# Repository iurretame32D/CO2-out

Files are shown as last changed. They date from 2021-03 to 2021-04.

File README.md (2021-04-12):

# CO2-OUT
Iurreta LHI ikastetxeko Mantentze-lan elektronikoa heziketa zikloko ikasleek proiektu moduluan egindako lana: CO2, hezetasuna eta tenperatura neurtu eta Lora bitarez TheThingsNetworkera bidali. NodeRed erabiliz datuak erakutsi.

Iurreta Electronic Vocational Training student project: measurement of CO2, humidity and temperature. LORA TTN Communications. Dashboard via NodeRed.

## The Things Network gateway

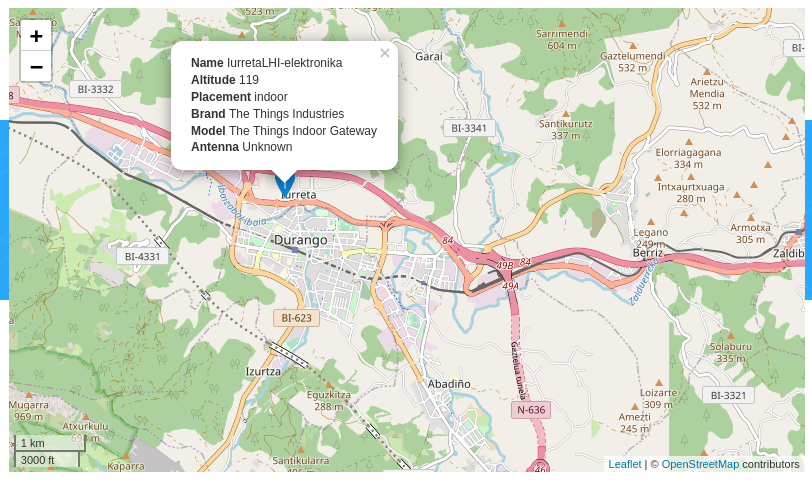
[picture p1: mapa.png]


## Bloke Diagrama / Block diagram 

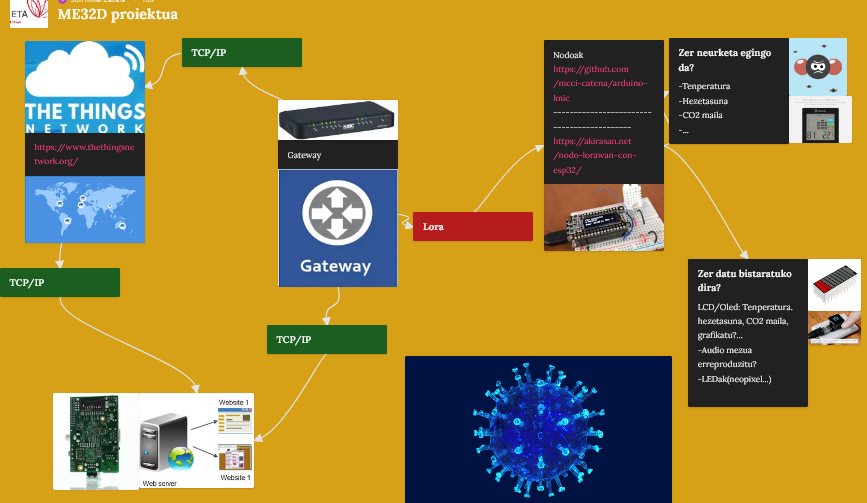
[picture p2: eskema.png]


## Emaitzak / Result
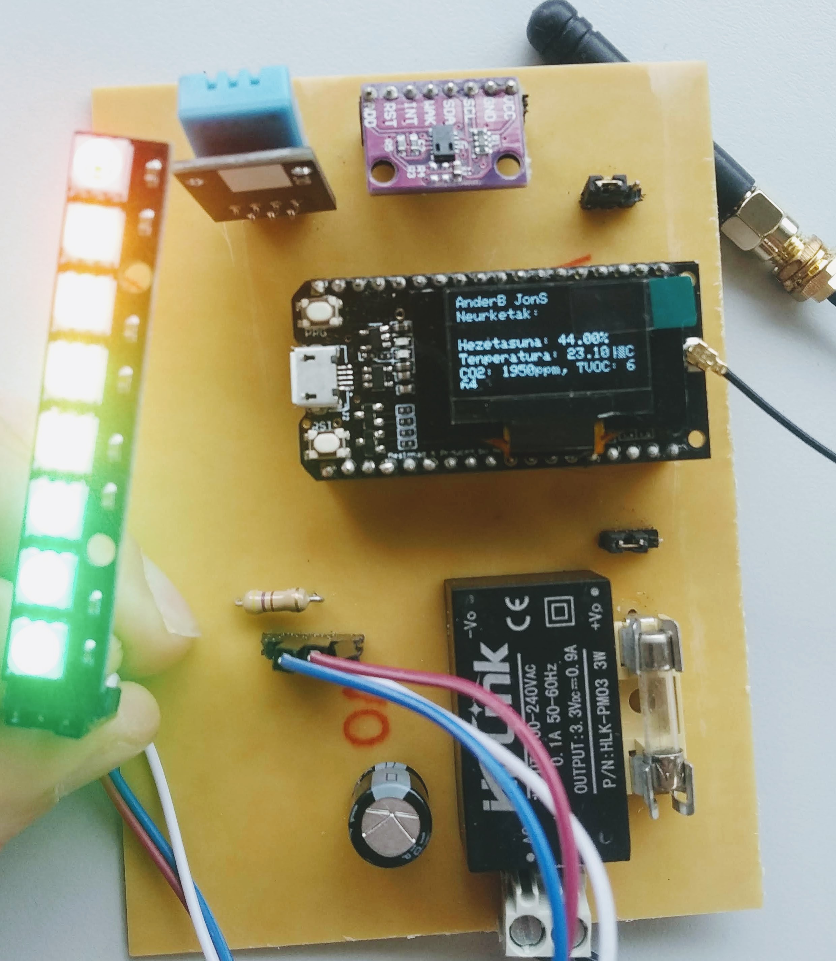
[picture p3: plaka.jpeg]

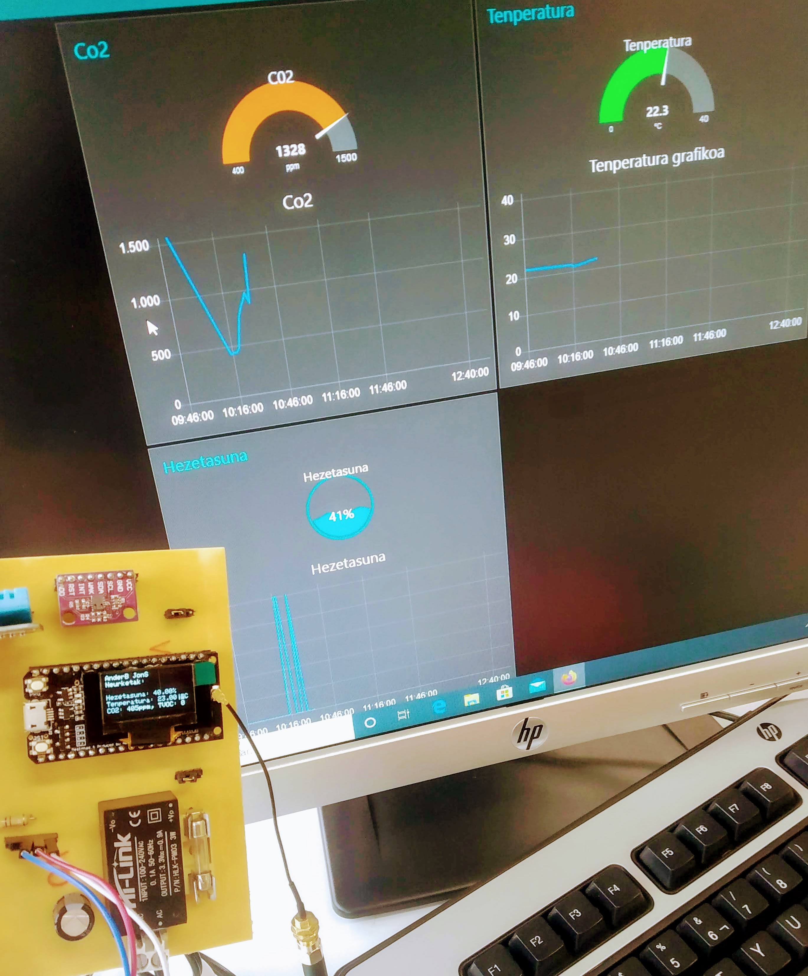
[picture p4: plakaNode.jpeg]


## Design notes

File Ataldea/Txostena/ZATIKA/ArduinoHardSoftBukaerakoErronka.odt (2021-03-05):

# Arduino nano pinen esleipena

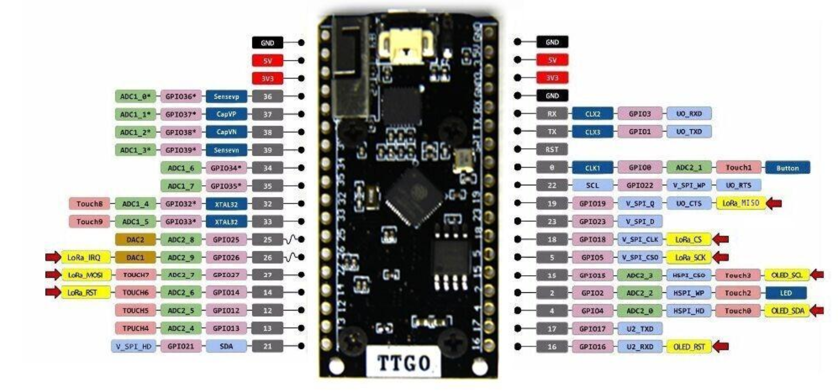
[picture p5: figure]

## 1.8. ESP-32 hardware eta software baliabideak

DIGITALA | KOMUNIKAZIOAK | GAINERAKOAK | ERABILERA
GPI0/GPO0
GPI1/GPO1 | UART TxD | | Ordenagailuarekin komunikatzeko (Serial) Datuak bidali
GPI2/GPO2
GPI3/GPO3 | UART RxD | | Ordenagailuarekin komunikatzeko (Serial) Datuak jaso
GPI4/GPO4 | SDA | | OLED_SDA ETA CJMCU-811 (CO2_Sentsorea)
GPI5/GPO5 | SPI CSO | | LORA_SCK ETA CJMCU-811 (CO2_Sentsorea)
GPI12/GPO12
GPI13/GPO13 | | | CJMCU-2812-8(Led Neopixel)
GPI14/GPO14 | | | LORA_RST
GPI15/GPO15 | SCL | | OLED_SCL
GPI16/GPO16 | U2 RXD | | OLED_RST
GPI17/GPO17 | U2 TXD | | DHT11 (Tenperatura eta Hezetasuna)
GPI18/GPO18 | SPI CLK | | LORA_CS
GPI19/GPO19 | | | LORA_MISO
GPI21/GPO21 | SDA | | CJMCU-811 (CO2_Sentsorea)
GPI22/GPO22 | SCL | | CJMCU-811 (CO2_Sentsorea)
GPI23/GPO23
GPI24/GPO24
GPI25/GPO25
GPI26/GPO26 | | | LORA_IRQ
GPI27/GPO27 | | | LORA_MOSI
GPI32/GPO32
GPI33/GPO33
GPI34/GPO34
GPI35/GPO35
GPI36/GPO36
GPI37/GPO37
GPI38/GPO38
GPI39/GPO39

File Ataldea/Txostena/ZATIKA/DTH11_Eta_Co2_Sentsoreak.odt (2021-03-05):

## 1.1 Tenperatura eta hezetasuna sentsorea

### Sarrera

DHT11 tenperatura eta hezetasun digitaleko sentsore bat da, kostu txikikoa. Hezetasun-sentsore kapazitibo bat eta termistor bat erabiltzen ditu inguruko airea neurtzeko, eta datuak seinale digital baten bidez erakusten ditu datu-pinuan (ez dago sarrerako pinu analogikorik).

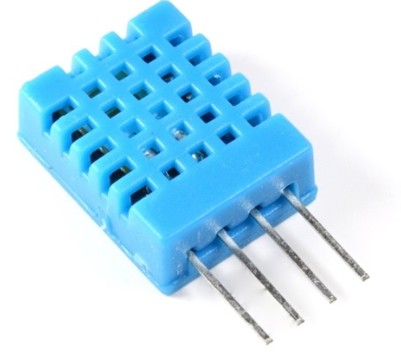
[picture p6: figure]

| Operazio-tentsioa:3V-5VDC. Tenperatura neurtzeko tartea: 0 eta 50 ° C bitartean. Tenperatura neurtzeko doitasuna: ± 2.0 ° c Denbora-ebazpena: 0.1 ° C. Hezetasuna neurtzeko tartea:% 20tik% 90era Rh. Hezetasuna neurtzeko zehaztasuna:% 5 Rh. Hezetasunaren ebazpena: Rh% 1. Sensida-denbora: 1 seg.

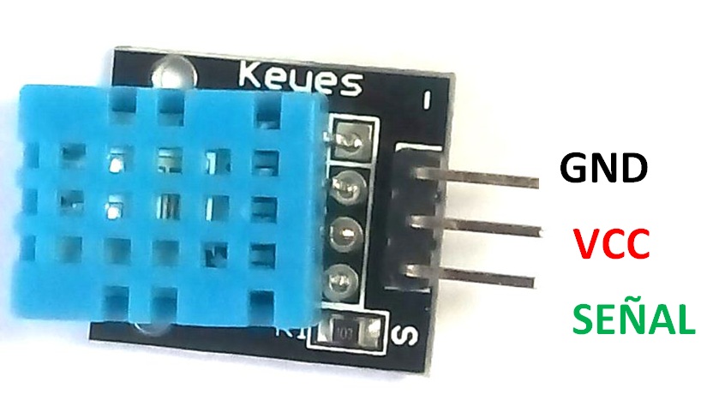
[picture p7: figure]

https://www.mouser.com/datasheet/2/758/DHT11-Technical-Data-Sheet-Translated-Version-1143054.pdf

https://www.mouser.com/datasheet/2/758/DHT11-Technical-Data-Sheet-Translated-Version-1143054.pdf

### Eskema elektronikoak

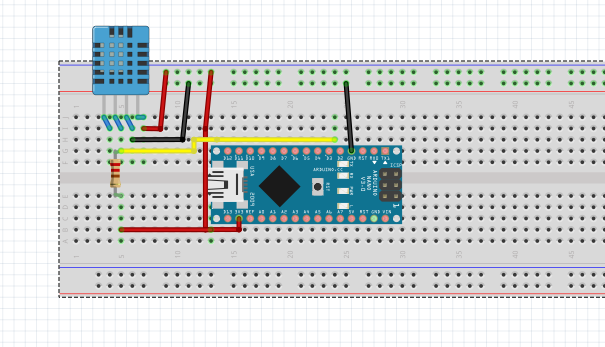
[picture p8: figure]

### Sentsorearen edo shieldaren pinout-a

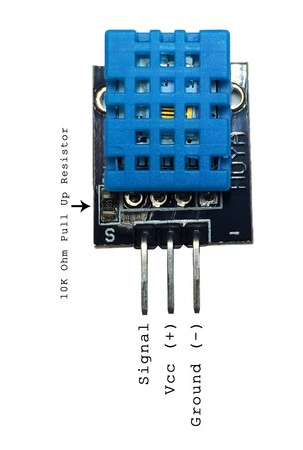
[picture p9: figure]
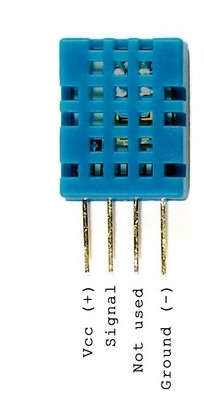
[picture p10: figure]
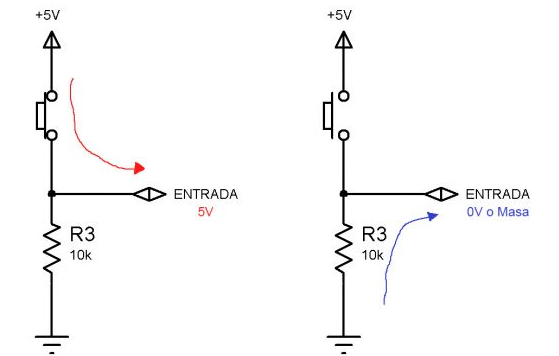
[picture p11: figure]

Sentsore hau funtzionatzeko erresitentzia bat erabili behar dugu. Erresistentzia pull up moduan jarriko dugu.

### Oinarrizko programa

Behar dugun libreria isntalatu. https://github.com/adafruit/Adafruit_Sensor

https://github.com/adafruit/DHT-sensor-library

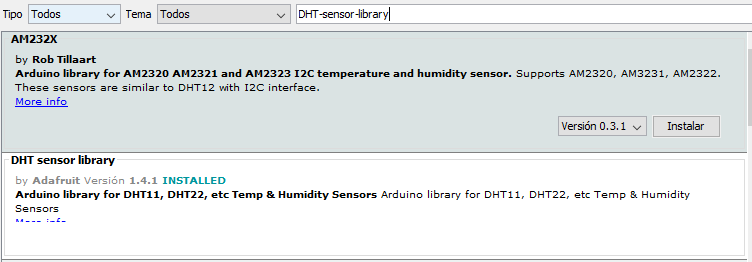
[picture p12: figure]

/*

Programaren izena: DHTtester_JON_MIKEL

Egilea: JON eta MIKEL Data: 22/02/2021

Zeregina: DHT sentsorearekin tenperatura eta hezetazuna neurtzea.

Adibide hau domeinu publikokoa da.

Programaren egoera: Egiaztatzeko/Egiaztatuta

Egiaztatutako plakak: hasiera batean Nano-arekin konprobatu dugu.

*/

/*-----( LIBURUTEGIAK )----*/

// - DHT Sensor Library: https://github.com/adafruit/DHT-sensor-library

// - Adafruit Unified Sensor Lib: https://github.com/adafruit/Adafruit_Sensor

#include <DHT.h>

#include <DHT_U.h>

#include "DHT.h"

#define DHTPIN 2 // DHT sentsoreari lotutako Digital pin

//Erabili pinak 3, 4, 5, 12, 13 edo 14.

//Pin 15ek funtziona dezake, baina DHT deskonektatu egin behar da programazioan.

/*-----( KONSTANTEAK )-----*/

#define DHTTYPE DHT11 // DHT 11

//#define DHTTYPE DHT22 // DHT 22 (AM2302), AM2321

//#define DHTTYPE DHT21 // DHT 21 (AM2301)

// Connect pin 1 (ezkerrean) of the sensor to +5V

//3.3V logika duen taula bat Arduino Due batek pin 1 konektatzen badu

//5V ordez, 3.3V!

//Zure DHTPIN DOKTOREARI

//X/Connect pin 4 (eskuinaldean)

//Connect a 10K resistor from pin 2 (datuak) to pin 1 (boterea)

//DHT sentsorea.

//Liburutegi honen bertsio zaharragoek hirugarren parametro bat eraman zuten.

//Parametro hau ez da beharrezkoa prozesadore azkarragoentzat.

//DHT irakurgailuaren algoritmoa prozesu azkarragoetan lan egitera egokitzen da.

//DHT dht(DHTPIN, DHTTYPE);

void setup() {

Serial.begin(9600);

Serial.println(F("DHTxx test!"));

dht.begin();

}

void loop() {

// Wait a few seconds between measurements.

delay(2000);

// Reading temperature or humidity takes about 250 milliseconds!

// Sensor readings may also be up to 2 seconds 'old' (its a very slow sensor)

float h = dht.readHumidity();

// Read temperature as Celsius (the default)

float t = dht.readTemperature();

// Read temperature as Fahrenheit (isFahrenheit = true)

float f = dht.readTemperature(true);

// Check if any reads failed and exit early (to try again).

if (isnan(h) || isnan(t) || isnan(f)) {

Serial.println(F("Failed to read from DHT sensor!"));

return;

}

// Compute heat index in Fahrenheit (the default)

float hif = dht.computeHeatIndex(f, h);

// Compute heat index in Celsius (isFahreheit = false)

float hic = dht.computeHeatIndex(t, h, false);

Serial.print(F("hezetasuna: "));

Serial.print(h);

Serial.print(F("% Temperatura: "));

Serial.print(t);

Serial.print(F("°C "));

Serial.print(f);

Serial.print(F("°F Bero-indizea: "));

Serial.print(hic);

Serial.print(F("°C "));

Serial.print(hif);

Serial.println(F("°F"));

}

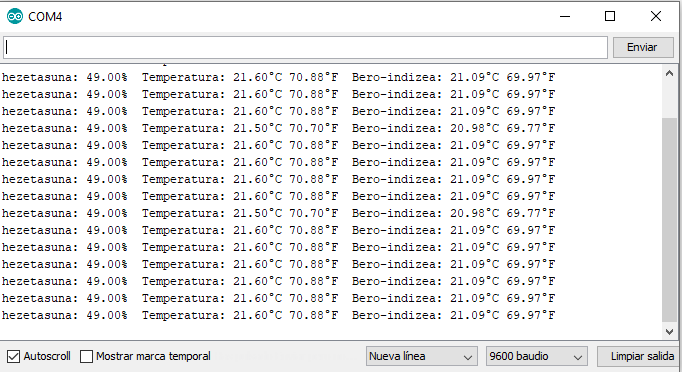
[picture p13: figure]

### Oinarrizko programa funtzioak bihurtuta

/* Funtzioa: int DTH11sentsorea (int zeinPin)

* Zeregina: DTH11 sentsorean temperatura eeta hezetasuna naurtzen du.

* Erabilitako liburutegiak: DTH11DHT Sensor Library eta Adafruit

* Liburutegia nondik hartuta: https://github.com/adafruit/Adafruit_Sensor // https://github.com/adafruit/DHT-sensor-library

* Bueltatzen duena: ezer

* Sartutako parametroak:

* int

*

* */

void DTH11sentsoreaSETUP (void){

Serial.println(F("DHTxx test!"));

dht.begin();

}

/* Funtzioa: int DTH11sentsorea (int zeinPin)

* Zeregina: DTH11 sentsorean temperatura eeta hezetasuna naurtzen du.

* Erabilitako liburutegiak: DTH11DHT Sensor Library eta Adafruit

* Liburutegia nondik hartuta: https://github.com/adafruit/Adafruit_Sensor // https://github.com/adafruit/DHT-sensor-library

* Bueltatzen duena: ezer

* Sartutako parametroak:

* int

*

* */

void DTH11sentsoreaLOOP (void){

// Wait a few seconds between measurements.

delay(2000);

// Reading temperature or humidity takes about 250 milliseconds!

// Sensor readings may also be up to 2 seconds 'old' (its a very slow sensor)

float h = dht.readHumidity();

// Read temperature as Celsius (the default)

float t = dht.readTemperature();

// Read temperature as Fahrenheit (isFahrenheit = true)

float f = dht.readTemperature(true);

// Check if any reads failed and exit early (to try again).

if (isnan(h) || isnan(t) || isnan(f)) {

Serial.println(F("Failed to read from DHT sensor!"));

return;

}

// Compute heat index in Fahrenheit (the default)

float hif = dht.computeHeatIndex(f, h);

// Compute heat index in Celsius (isFahreheit = false)

float hic = dht.computeHeatIndex(t, h, false);

Serial.print(F("hezetasuna: "));

Serial.print(h);

Serial.print(F("% Temperatura: "));

Serial.print(t);

Serial.print(F("°C "));

Serial.print(f);

Serial.print(F("°F Bero-indizea: "));

Serial.print(hic);

Serial.print(F("°C "));

Serial.print(hif);

Serial.println(F("°F"));

}

### Material zerrenda

Izena | Kopurua | Oharrak edota ezaugarri bereziak
DHT11 | 1 | Errezistentzia erabilitzen dugu. (PULL UP)
ARDUINO NANO | 1 | Sentsorea probetako erabiltzen dugu.

### Gorabeherak

### Estekak

https://steve.fi/hardware/temperature/

https://www.zonamaker.com/electronica/intro-electronica/teoria/resistencias-de-pull-up-y-pull-down

https://forum.fritzing.org/t/heltec-dev-boards/8112

https://fritzing.org/projects/dht11-temp-and-humidity-sensor

## CO2 sentsorea

### Sarrera

CCS811 sentsore bat da barneko airearen kalitatea neurtzeko, eta erraz erabil dezakegu Arduino bezalako prozesadore batekin batera.
Barneko airearen kalitatea zehazteko, CCS811 MOX (Metal-Oxide) sentsore multigas bat da, karbono monoxidoa (Co) eta konposatu lurrunkorrak (VOCs) neurtzea barne hartzen duena, hala nola etanola, aminak edo hidrokarburo aromatikoak. Horien bidez, CCS811k karbono dioxido baliokidearen (eCO2) kantitatea zehaztu dezake. Neurketa-tartea 400 eta 8192 ppm artekoa da eCO2-n eta 0 eta 1187 ppb artekoa TVOCen.

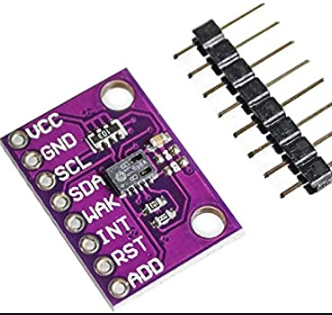
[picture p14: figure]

| Konposatu organiko lurrunkorra guztira (TVOC), milioi bakoitzeko 0 eta 1187 zati bitartean detektatzen dituena ECO2ren detekzioa, 400etik 8,192ra milioiko. Bost funtzionamendu-modu MCU integratua I2C interfaze digital estandarra Kontsumo txikiko moduak Elikadura: 3.3V a 5V Neurriak: 21 x 18 x 3 milimetro Pisua: 1.2 gramo

Datasheet-ak ez du neurketaren zehaztasunari buruzko daturik ematen.

https://cdn.sparkfun.com/assets/2/c/c/6/5/CN04-2019_attachment_CCS811_Datasheet_v1-06.pdf

### Eskema elektronikoak

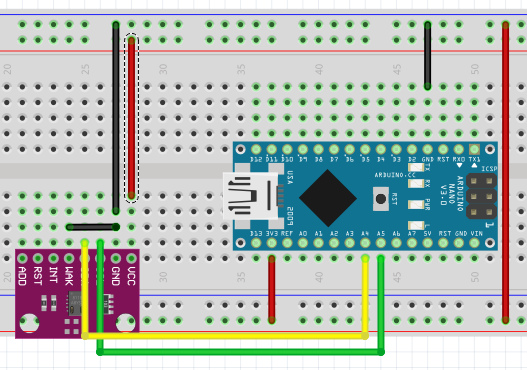
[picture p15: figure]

### Sentsorearen edo shieldaren pinout-a

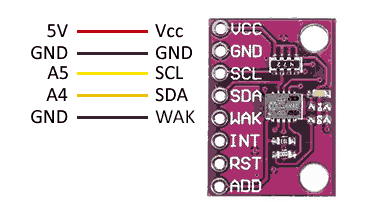
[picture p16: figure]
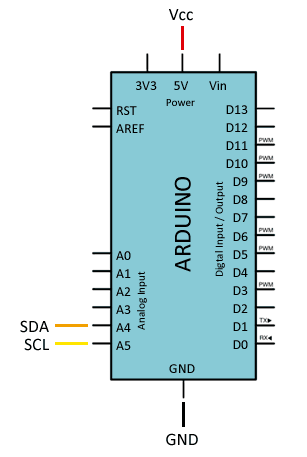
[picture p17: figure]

### Oinarrizko programa

Behar dugun lebreria istalatu. //https://github.com/adafruit/Adafruit_CCS811

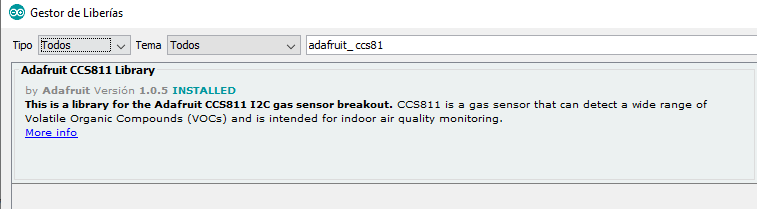
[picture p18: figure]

/*

Programaren izena: DHTtester_JON_MIKEL

Egilea: JON eta MIKEL Data: 22/02/2021

Zeregina: DHT sentsorearekin tenperatura eta hezetazuna neurtzea.

Adibide hau domeinu publikokoa da.

Programaren egoera: Egiaztatzeko/Egiaztatuta

Egiaztatutako plakak: hasiera batean Nano-arekin konprobatu dugu.

*/

/*-----( LIBURUTEGIAK )----*/

#include "Adafruit_CCS811.h" //https://github.com/adafruit/Adafruit_CCS811

Adafruit_CCS811 ccs;

void setup() {

Serial.begin(9600);

Serial.println("CCS811 test");

if(!ccs.begin()){

Serial.println("Failed to start sensor! Please check your wiring.");

while(1);

}

// Wait for the sensor to be ready

while(!ccs.available());

}

void loop() {

if(ccs.available()){

if(!ccs.readData()){

//Serial.println(ccs.calculateTemperature());

Serial.print("ºC, CO2: ");

Serial.print(ccs.geteCO2());

Serial.print("ppm, TVOC: ");

Serial.println(ccs.getTVOC());

}

else{

Serial.println("ERROR!");

while(1);

}

}

delay(500);

}

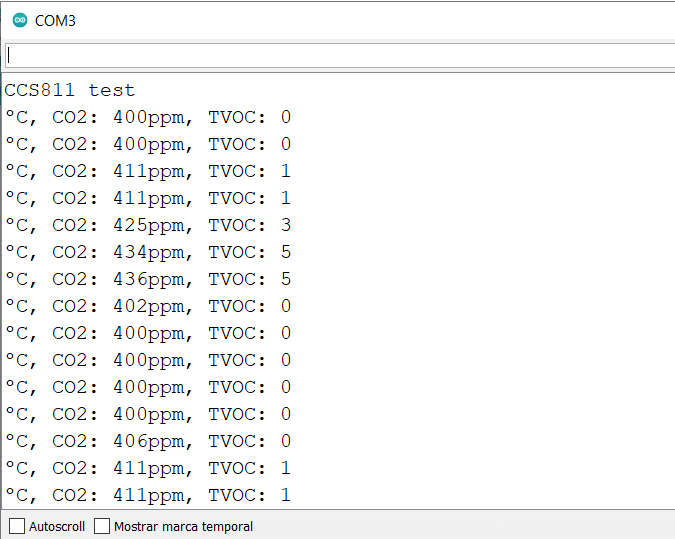
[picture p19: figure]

### Oinarrizko programa funtzioak bihurtuta

/* Funtzioa: void CO2sentsorea (void)

* Zeregina:CO2 sentsorean naurtzea du.

* Erabilitako liburutegiak: DTH11DHT Sensor Library eta Adafruit

* Liburutegia nondik hartuta://https://github.com/adafruit/Adafruit_CCS811

* Bueltatzen duena: ezer

* Sartutako parametroak:

* int

*

* */

void CO2sentsoreaSETUP (void){

Serial.println("CCS811 test");

if(!ccs.begin()){

Serial.println("Failed to start sensor! Please check your wiring.");

while(1);

}

// Wait for the sensor to be ready

while(!ccs.available());

}

/* Funtzioa: void CO2sentsorea (void)

* Zeregina:CO2 sentsorean naurtzea du.

* Erabilitako liburutegiak: DTH11DHT Sensor Library eta Adafruit

* Liburutegia nondik hartuta://https://github.com/adafruit/Adafruit_CCS811

* Bueltatzen duena: ezer

* Sartutako parametroak:

* int

*

* */

void CO2sentsoreaLOOP (void){

if(ccs.available()){

if(!ccs.readData()){

//Serial.println(ccs.calculateTemperature());

Serial.print("CO2: ");

Serial.print(ccs.geteCO2());

Serial.println("ppm");

Serial.print("TVOC: ");

Serial.println(ccs.getTVOC());

}

else{

Serial.println("ERROR!");

while(1);

}

}

delay(500);

}

### Material zerrenda

Izena | Kopurua | Oharrak edota ezaugarri bereziak
CO2 (Sentsorea) | 1
ARDUINO NANO | 1 | Sentsorea probetako erabiltzen dugu.

### Gorabeherak

### Estekak

https://www.luisllamas.es/medir-calidad-del-aire-y-co2-con-ccs811-y-arduino/

https://tienda.bricogeek.com/sensores-gas/1508-sensor-de-calidad-del-aire-ccs811-voc-y-co2.html

http://digitalconcepts.net.au/fritzing/index.php?op=parts

20-21 ikasturtea Erronkaren azpiatala

IURRETA LHI Ikastetxea 11. orrialdea

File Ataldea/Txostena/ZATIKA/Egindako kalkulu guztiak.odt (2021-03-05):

# Egindako kalkulu guztiak

## Elikatze-iturriaren kalkuluak

Gure osagai guztiak zenbateko elikadura behar dituen eta zenbat mA erabiltzen dituen. Taula honetan adierazten dugu.

PLAKAKO ELIKADURA | | | | | KANPOKO ELIKADURA | | ERABILERA
VIN | 5V | 3V3 | GND | RESET | V | mA
| | X | | | 3V3 | 20mA | TT-GO-ESP32
| | X | | | | 4.5mA | CCS811 (CO2 Sentsorea)
| | X | | | | 2.5mA | DHT11 (Tenperatura eta Hezetasuna Sentsorea)
| | X | | | | 900mA | Neopixel
12 voltio | | | | | 220 | 1100%20220mA | Bateria DC

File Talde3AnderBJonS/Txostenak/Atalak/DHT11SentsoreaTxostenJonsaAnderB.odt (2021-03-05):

## DHT-11

### Sarrera

DHT-11 erabiliko ditugun sentsoreetako bat izango da, sentsore hau tenperatura eta hezetasuna neurtzuko balio du, gure kasuan erabiliko duguna 3 pin ditu, eskumako irudian ikusten denez.

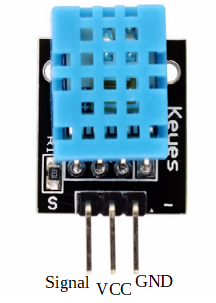
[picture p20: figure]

Tenperatura ºCtan neurtzen du eta hezetasuna %tan.

Kostu txikiko eta erabiltzeko erraza den sentsorea da.Hezetasun kapazitarioaren sentsorea eta termistore bat integratzen ditu inguruko airea neurtzeko, eta datuak seinale digital baten bidez erakusten ditu signal pinean (ez du irteera analogikorik).

Datasheet Link

https://components101.com/sites/default/files/component_datasheet/DHT11-Temperature-Sensor.pdf

Ezaugarriak:

- Kontsumoa = 2,5mA
- Irteera seinalea = Digitala
- Tenperatura maila = 0ºC – 50ºC
- Hezetasun maila = 20 % - 90 %

### Eskema elektronikoak

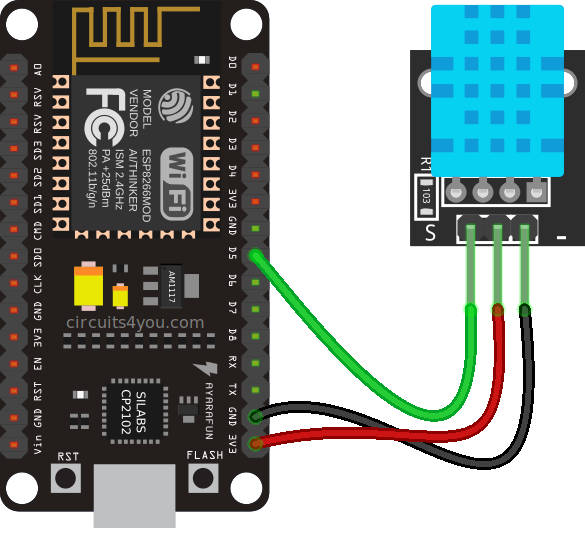
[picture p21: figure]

### Sentsorearen edo shieldaren pinout-a

Berezitasunik balego adierazi hemen (pull-up erresistentziak, tentsio balioen mugak...)

### Oinarrizko programa

#include "DHT.h"

// Uncomment whatever type you're using!

#define DHTTYPE DHT11 // DHT 11

//#define DHTTYPE DHT22 // DHT 22 (AM2302), AM2321

//#define DHTTYPE DHT21 // DHT 21 (AM2301)

// Connect pin 1 (on the left) of the sensor to +5V

// NOTE: If using a board with 3.3V logic like an Arduino Due connect pin 1

// to 3.3V instead of 5V!

// Connect pin 2 of the sensor to whatever your DHTPIN is

// Connect pin 4 (on the right) of the sensor to GROUND

// Connect a 10K resistor from pin 2 (data) to pin 1 (power) of the sensor

const int DHTPin = 5; // what digital pin we're connected to

DHT dht(DHTPin, DHTTYPE);

void setup() {

Serial.begin(9600);

Serial.println("DHTxx test!");

dht.begin();

}

void loop() {

// Wait a few seconds between measurements.

delay(2000);

// Reading temperature or humidity takes about 250 milliseconds!

float h = dht.readHumidity();

float t = dht.readTemperature();

if (isnan(h) || isnan(t)) {

Serial.println("Failed to read from DHT sensor!");

return;

}

Serial.print("Humidity: ");

Serial.print(h);

Serial.print(" %\t");

Serial.print("Temperature: ");

Serial.print(t);

Serial.println(" *C ");

}

### Oinarrizko programa funtzioak bihurtuta

Nagusia:

/*-----( LIBURUTEGIAK )----*/

//CO2

#include "Adafruit_CCS811.h"

Adafruit_CCS811 ccs;

//DHT11

#include "DHT.h"

/*-----( KONSTANTEAK )-----*/

#define DHTTYPE DHT11 // DHT 11

const int DHTPin = 5; // what digital pin we're connected to

/*-----( OBJETUAK )-----*/

//DHT-11

DHT dht(DHTPin, DHTTYPE);

/*-----( ALDAGAIAK )----*/

//Programa osoan zehar erabiliko diren aldagai orokorrak

//Komunikazio serierako aldagaiak

/*-----( FUNTZIOAK )----*/

float dhtSentsoreaLoop(void);

void CO2SentsoreaLoop();

void C02SentsoreaSetup();

void dhtSentsoreaSetup();

void setup() {

// put your setup code here, to run once:

Serial.begin(9600);

dhtSentsoreaSetup();

C02SentsoreaSetup();

}

void loop() {

dhtSentsoreaLoop();

CO2SentsoreaLoop();

}

// put your main code here, to run repeatedly:

CO2:

/* Funtzioa: CO2 sentsorea

* Zeregina: Funtzio honek C02 sentsoreak neurtutako balioak irakurtzeko

* Erabilitako liburutegiak: https://github.com/adafruit/Adafruit_CCS811

* Bueltatzen duena: C02 eta TVOC neurketa

* Sartutako parametroak: ezer

* */

void C02SentsoreaSetup()

{

Serial.println("CCS811 test");

if(!ccs.begin()){

Serial.println("Failed to start sensor! Please check your wiring.");

while(1);

}

while(!ccs.available());

}

void CO2SentsoreaLoop() {

if(ccs.available()){

if(!ccs.readData()){

Serial.print("CO2: ");

Serial.print(ccs.geteCO2());

Serial.print("ppm, TVOC: ");

Serial.println(ccs.getTVOC());

}

else{

Serial.println("ERROR!");

while(1);

}

}

delay(500);

}

DHT-11:

/* Funtzioa: DHT-11 sentsorea

* Zeregina: Funtzio honek DHT-11 sentsoreak neurtutako balioak irakurtzeko

* Erabilitako liburutegiak: https://github.com/adafruit/DHT-sensor-library

* Bueltatzen duena: Tenperatura eta hezetasun neurketa

* Sartutako parametroak: ezer

* */

void dhtSentsoreaSetup()

{

Serial.println("DHTxx test!");

dht.begin();

}

float dhtSentsoreaLoop(void) {

// Wait a few seconds between measurements.

delay(2000);

// Reading temperature or humidity takes about 250 milliseconds!

float h = dht.readHumidity();

float t = dht.readTemperature();

if (isnan(h) || isnan(t)) {

Serial.println("Failed to read from DHT sensor!");

return;

}

Serial.print("Humidity: ");

Serial.print(h);

Serial.print(" %\t");

Serial.print("Temperature: ");

Serial.print(t);

Serial.println(" *C ");

}

### Material zerrenda

Nahi duzuen formatuan, sistema hau gauzatzeko material zerrenda. Gutxienez, azpiko taulan agertzen diren atalak agertu behar dira:

Izena | Kopurua | Oharrak edota ezaugarri bereziak
DHT-11 | 1 | 3 pin
ESP32 kontrolagailua | 1 | Nodo

### Gorabeherak

Ez ditugu izan gorabeherarik atal honetan

ME3Titulua

# ME3Kapitulua

## ME3Azpikapitulua1

### ME3Azpikapitulua2

#### ME3Azpikapitulua3

##### ME3Azpikapitulua4

###### ME3Azpikapitulua5

###### ME3Azpikapitulua6

ME3Arrunta

- ME3Buleta1

ME3Taula

ME3IrudiAzpi

20-21 ikasturtea Erronkaren azpiatala

IURRETA LHI Ikastetxea 7. orrialdea

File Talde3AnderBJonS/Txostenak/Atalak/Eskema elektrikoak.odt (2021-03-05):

# Eskema elektrikoak

Kicad eskema

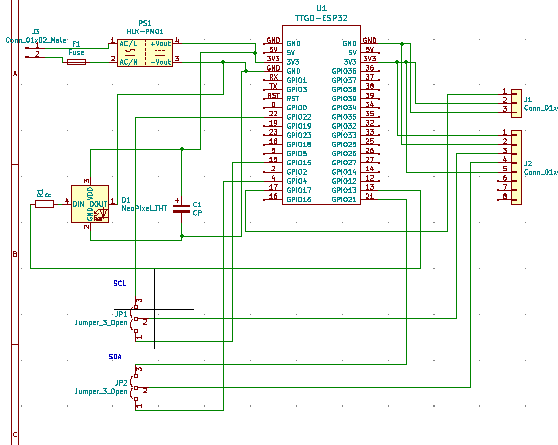
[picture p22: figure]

PCB eskema

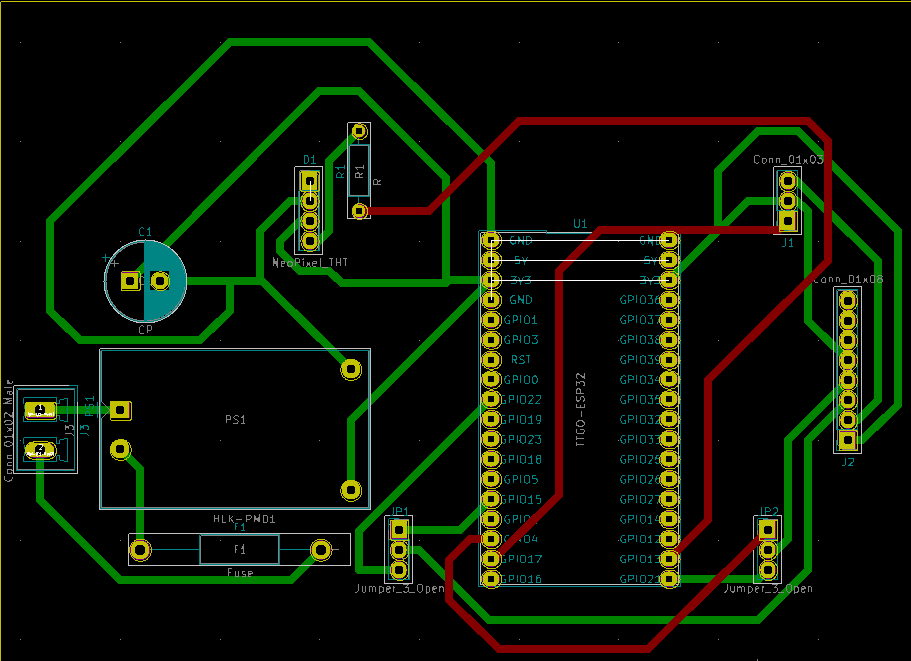
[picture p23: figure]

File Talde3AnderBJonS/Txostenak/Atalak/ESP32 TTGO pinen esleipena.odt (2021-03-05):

# ESP32 TTGO pinen esleipena

PLAKAKO ELIKADURA | | | | | KANPOKO ELIKADURA | | ERABILERA
VIN | 5V | 3V3 | GND | RESET | V | mA
| | | | | 3,3 | 20 | TTGO Lora
| | X | | | | 2,5 | DHT11 (Tenperatura eta Hezetasuna)
| | X | | | | 10 | CJMCU-811(CO2_Sentsorea)
| | X | | | | 480 | LED NEOPIXEL
| | | | | 220 V | 900 | HLK-PM03 AC-DC 220 V a 3,3V

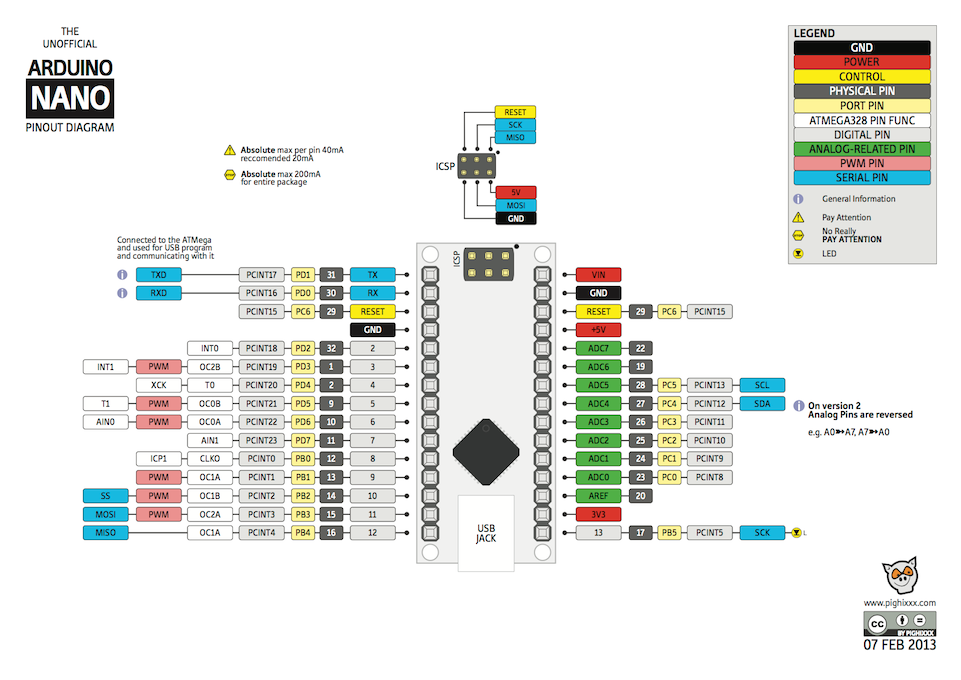
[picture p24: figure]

DIGITALA | KOMUNIKAZIOAK | GAINERAKOAK | ERABILERA
GPI0/GPO0
GPI1/GPO1 | UART TxD | | Ordenagailuarekin komunikatzeko (Serial) Datuak jaso
GPI2/GPO2
GPI3/GPO3 | UART RxD | | Ordenagailuarekin komunikatzeko (Serial) Datuak bidali
GPI4/GPO4 | SDA | | OLED_SDA--CJMCU-811(CO2_Sentsorea)
GPI5/GPO5 | SPI CSO | | LORA_SCK
GPI12/GPO12
GPI13/GPO13 | | | LED NEOPIXEL
GPI14/GPO14 | | | LORA_RST
GPI15/GPO15 | SCL | | OLED_SCL--CJMCU-811(CO2_Sentsorea)
GPI16/GPO16 | U2 RXD | | OLED_RST
GPI17/GPO17 | U2 TXD | | DHT11 (Tenperatura eta Hezetasuna)
GPI18/GPO18 | SPI CLK | | LORA_CS
GPI19/GPO19 | | | LORA_MISO
GPI21/GPO21 | SDA(jumper) | | CJMCU-811(CO2_Sentsorea)
GPI22/GPO22 | SCL(jumper) | | CJMCU-811(CO2_Sentsorea)
GPI23/GPO23
GPI24/GPO24
GPI25/GPO25
GPI26/GPO26 | | | LORA_IRQ
GPI27/GPO27 | | | LORA_MOSI
GPI32/GPO32
GPI3/GPO33
GPI34/GPO34
GPI35/GPO35

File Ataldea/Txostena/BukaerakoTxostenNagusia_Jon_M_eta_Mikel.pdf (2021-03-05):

# LORA

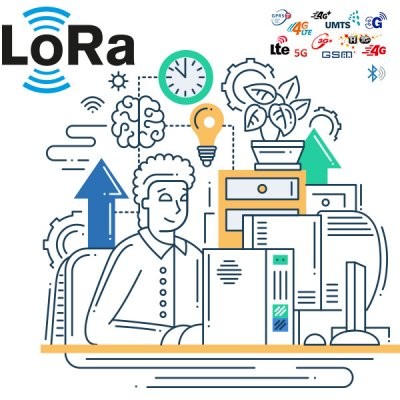
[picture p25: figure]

Egileak

Jon M eta Mikel

1. orrialdea
lan hau IURRETA LHIIk sortu du eta Creative Commons lizentzia (https://creativecommons.org/licenses/by-nc/4.0/deed.eu) baten mende dago.

## Ziklo bukaerako proiektua: aurkibidea

2. orrialdea

# 1 Erronkaren planteamentua

Erronka honetan bidali digute co2, tenperatura eta hezetasuna neurtzea eta honek datuak prosesatzeko Lora esp32 kontrolagailua. Datu honekin lortu behar duguna da WEB SERVER batean irakur ahal izatea eta ona heltzeko hainbat pausu pasatu behar dugu. Lehenik datuak GATEWAY batera bidaltzea eta irakurtzea, ostean RASPERRRY locala sortu.
Erronka bukatzen dugunean github plataformara dena dokumentatu eta programa osoak igo beharko dugu.

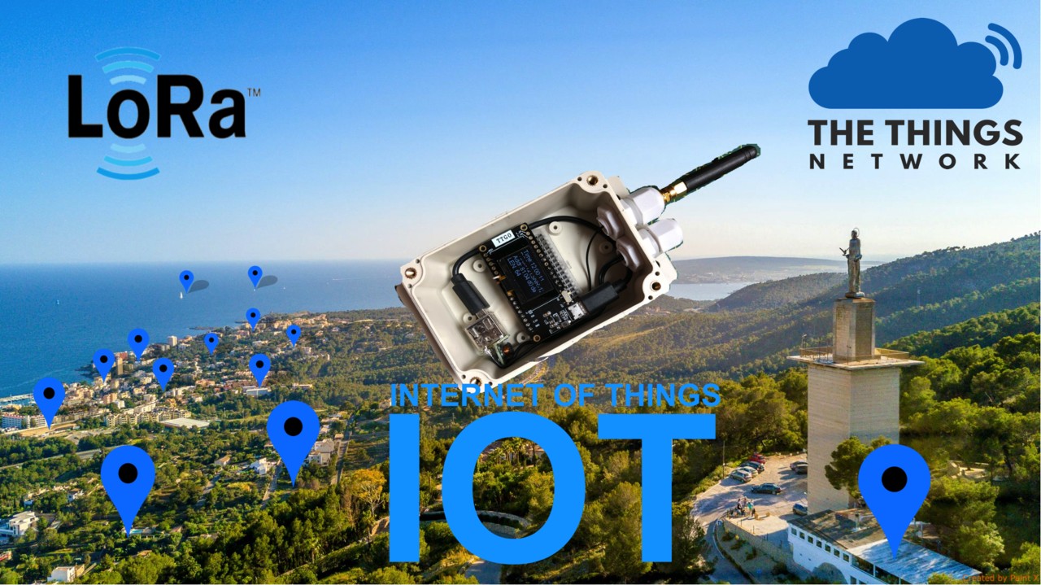
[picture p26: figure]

3. orrialdea

# 2 Bloke-diagramak

Lehen bertsioa izango da hau. Erronkaren amaieran igo egingo duzue azken bertsioa.

# 2.1 Softwarearen hasierako bloke-diagrama

Softwarea: geziekin, bloke bakoitza zelan eta zertarako erabiliko den azalduta azpian. Aldagaiak eta funtzioen izenak aurreikustea ere komeniko litzateke. Sekuentzia edo ordena inportantea dela kontutan izan.

4. orrialdea

# 2.2 Hardwarearen hasierako bloke-diagram

Hardwarea: geziekin, bloke bakoitza zelan eta zertarako erabiliko den azalduta azpian.

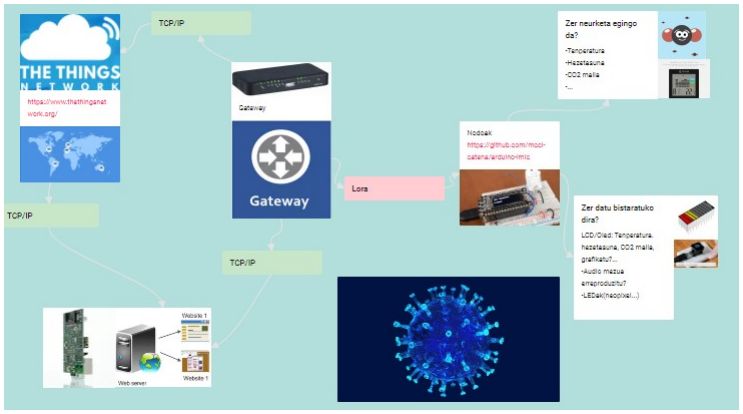
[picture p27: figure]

5. orrialdea

# 2.3 Softwarearen amaierako bloke-diagrama

Softwarea: geziekin, bloke bakoitza zelan eta zertarako erabiliko den azalduta azpian. Aldagaiak eta funtzioen izenak aurreikustea ere komeniko litzateke. Sekuentzia edo ordena inportantea dela kontutan izan.

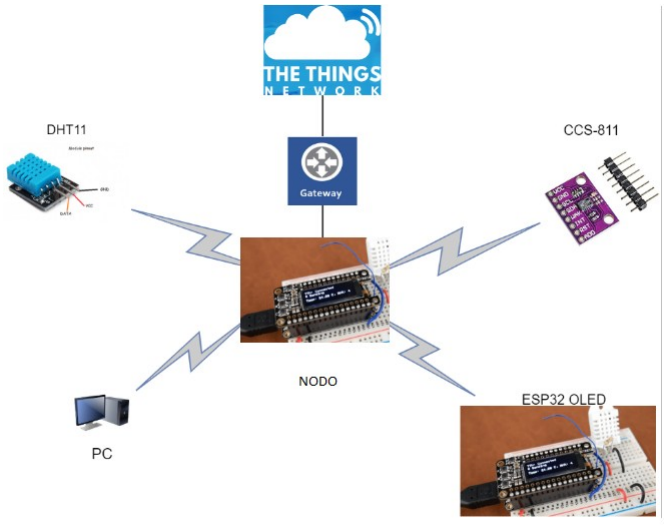
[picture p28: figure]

6. orrialdea

# 2.4 Hardwarearen amaierako bloke-diagrama

Hardwarea: geziekin, bloke bakoitza zelan eta zertarako erabiliko den azalduta azpian.


7. orrialdea

# 3 Haunarketa

## LORA ESP32

- Norabide bakarreko, norabide biko edo hedapen anitzeko lan-gaitasuna
- Interferentziekiko tolerantzia handia
- Sentsibilitate handia datuak jasotzeko (-168dB)
"Chirp" modulazioan oinarritua
- Kontsumo baxua (10 urtera arte bateria batekin)
- Luzera: 10-20 km
- Datuen transferentzia txikia (255 byte gehienez)
- Puntuz puntuko konexioa
- Lan maiztasunak: 868 Mhz Europan, 915 Mhz Amerikan eta 433 Mhz Asian
8. orrialdea

DH11

- DHT11 eta DHT22 (edo AM2302) sentsore familia bereko bi modelo dira, tenperatura eta hezetasuna aldi berean neurtzeko aukera ematen dutenak.
- Sentsore horiek barne-prozesadore bat dute, neurketa-prozesua egiten duena, eta neurketa seinale digital baten bidez ematen dute; beraz, oso erraza da neurketa Arduino bezalako mikroprozesadore batetik lortzea.
- Bi sentsoreek antzeko plastikozko kapsulatzea dute. Bi ereduak kolorearen arabera bereiz ditzakegu. DHT11ak karkasa urdin bat du, DHT22 sentsorearen kasuan, berriz, kanpoaldea zuria da.


9. orrialdea

## CCS811

- CCS811 AMS fabrikatzailearen sentsore bat da barneko airearen kalitatea neurtzeko, eta erraz erabil dezakegu Arduino bezalako prozesadore batekin batera.
- Barneko airearen kalitatea zehazteko, CCS811 MOX (Metal-Oxide) sentsore multigas bat da, karbono monoxidoa (Co) eta konposatu lurrunkorrak (VOCs) neurtzea barne hartzen duena, hala nola etanola, aminak edo hidrokarburo aromatikoak.
- Horien bidez, CCS811k karbono dioxido baliokidearen (eCO2) kantitatea zehaztu dezake. Neurketa-tartea 400 eta 8192 ppm artekoa da eCO2-n eta 0 eta 1187 ppb artekoa TVOCen. Datasheet-ak ez du neurketaren zehaztasunari buruzko daturik ematen.


10. orrialdea

# 4 Lora TTGO esp32

# 4.1 Sarrera

TTGO LoRa32 SX1276 OLED garapen plaka bat da, LoRa txip bat eta 0,96 hazbeteko OLED SSD1306 pantaila dituena. Gida honetan erakutsiko dizugu nola bidali eta jaso LoRa paketeak (puntuz puntuko komunikazioa) eta nola erabili OLED pantaila Arduino IDErekin.


11. orrialdea

# 4.2 Lora liburutegiak

Lora esp32 erabili ahal izateko hainbat librería instalatu behar dira eta orain esteka bidez eta argazki bidez adieraziko dizuet.

Asteko lora funtzionatzeko hainbat librería istalatu behar dira eta esteka honetatik pausuak jarraitzen atera ditugu:

https://randomnerdtutorials.com/ttgo-lora32-sx1276-arduino-ide/https://github.com/matthijskooijman/arduino-lmic.git

https://randomnerdtutorials.com/installing-the-esp32-board-in-arduino-ide-windows-instructions/


12. orrialdea

# 4.3 Lora probak

Lora probatzeko programa bat sartu diogu, nun programa hau 10segunduro mezuak bidaltzen ditu beste dispositibo batera.
/*********
Rui Santos
Complete project details at https://RandomNerdTutorials.com/ttgo-lora32-sx1276-arduino-ide/
*********/
//Libraries for LoRa
#include <SPI.h>

#include <LoRa.h>

//Libraries for OLED Display #include <Wire.h>
#include <Adafruit_GFX.h>

#include <Adafruit_SSD1306.h>

//define the pins used by the LoRa transceiver module #define SCK 5
#define MISO 19

#define MOSI 27

#define SS 18

#define RST 14

#define DIO0 26

//433E6 for Asia
//866E6 for Europe
//915E6 for North America
#define BAND 866E6

//OLED pins
#define OLED_SDA 4

#define OLED_SCL 15

#define OLED_RST 16

#define SCREEN_WIDTH 128 // OLED display width, in pixels #define SCREEN_HEIGHT 64 // OLED display height, in pixels

//packet counter
int counter = 0;
Adafruit_SSD1306 display(SCREEN_WIDTH, SCREEN_HEIGHT, &Wire, OLED_RST); void setup() {
//reset OLED display via software
13. orrialdea pinMode(OLED_RST, OUTPUT); digitalWrite(OLED_RST, LOW); delay(20);
digitalWrite(OLED_RST, HIGH);
//initialize OLED
Wire.begin(OLED_SDA, OLED_SCL);
if(!display.begin(SSD1306_SWITCHCAPVCC, 0x3c, false, false)) { // Address 0x3C for 128x32
Serial.println(F("SSD1306 allocation failed"));
for(;;); // Don't proceed, loop forever
}
display.clearDisplay();
display.setTextColor(WHITE); display.setTextSize(1);
display.setCursor(0,0);
display.print("LORA SENDER "); display.display();
//initialize Serial Monitor Serial.begin(115200);
Serial.println("LoRa Sender Test"); //SPI LoRa pins
SPI.begin(SCK, MISO, MOSI, SS); //setup LoRa transceiver module LoRa.setPins(SS, RST, DIO0);
if (!LoRa.begin(BAND)) {
Serial.println("Starting LoRa failed!"); while (1);
}
Serial.println("LoRa Initializing OK!"); display.setCursor(0,10);
display.print("LoRa Initializing OK!"); display.display();
delay(2000);
}
void loop() {
Serial.print("Sending packet: "); Serial.println(counter);
14. orrialdea

//Send LoRa packet to receiver LoRa.beginPacket();
LoRa.print("hello ");
LoRa.print(counter);
LoRa.endPacket();
display.clearDisplay();
display.setCursor(0,0);
display.println("LORA SENDER"); display.setCursor(0,20);
display.setTextSize(1);
display.print("LoRa packet sent."); display.setCursor(0,30);
display.print("Counter:"); display.setCursor(50,30);
display.print(counter);
display.display();
counter++;
delay(10000);}
15. orrialdea

Mezu honek jasotzeko beste programa bat kargatu behar da.
/*********
Rui Santos
Complete project details at https://RandomNerdTutorials.com/ttgo-lora32-sx1276-arduino-ide/
//Libraries for LoRa
#include <SPI.h>

#include <LoRa.h>

//Libraries for OLED Display #include <Wire.h>
#include <Adafruit_GFX.h>

#include <Adafruit_SSD1306.h>

//define the pins used by the LoRa transceiver module #define SCK 5
#define MISO 19

#define MOSI 27

#define SS 18

#define RST 14

#define DIO0 26

//433E6 for Asia
//866E6 for Europe
//915E6 for North America
#define BAND 866E6

//OLED pins
#define OLED_SDA 4

#define OLED_SCL 15

#define OLED_RST 16

#define SCREEN_WIDTH 128 // OLED display width, in pixels

#define SCREEN_HEIGHT 64 // OLED display height, in pixels Adafruit_SSD1306 display(SCREEN_WIDTH, SCREEN_HEIGHT, &Wire, OLED_RST); String LoRaData;

void setup() {
//reset OLED display via software
pinMode(OLED_RST, OUTPUT); digitalWrite(OLED_RST, LOW); delay(20);
digitalWrite(OLED_RST, HIGH);
16. orrialdea

//initialize OLED
Wire.begin(OLED_SDA, OLED_SCL);
if(!display.begin(SSD1306_SWITCHCAPVCC, 0x3c, false, false)) { // Address 0x3C for 128x32
Serial.println(F("SSD1306 allocation failed"));
for(;;); // Don't proceed, loop forever
}
display.clearDisplay();
display.setTextColor(WHITE); display.setTextSize(1);
display.setCursor(0,0);
display.print("LORA RECEIVER "); display.display();
//initialize Serial Monitor Serial.begin(115200);
Serial.println("LoRa Receiver Test"); //SPI LoRa pins
SPI.begin(SCK, MISO, MOSI, SS); //setup LoRa transceiver module LoRa.setPins(SS, RST, DIO0);
if (!LoRa.begin(BAND)) {
Serial.println("Starting LoRa failed!"); while (1);
}
Serial.println("LoRa Initializing OK!"); display.setCursor(0,10);
display.println("LoRa Initializing OK!"); display.display();
}
void loop() {
//try to parse packet
int packetSize = LoRa.parsePacket(); if (packetSize) {
//received a packet
Serial.print("Received packet "); //read packet
while (LoRa.available()) {
17. orrialdea

LoRaData = LoRa.readString(); Serial.print(LoRaData); }
//print RSSI of packet
int rssi = LoRa.packetRssi(); Serial.print(" with RSSI "); Serial.println(rssi);
// Dsiplay information
display.clearDisplay();
display.setCursor(0,0);
display.print("LORA RECEIVER"); display.setCursor(0,20);
display.print("Received packet:"); display.setCursor(0,30);
display.print(LoRaData);
display.setCursor(0,40);
display.print("RSSI:");
display.setCursor(30,40);
display.print(rssi);
display.display();
}


18. orrialdea

# 4.4 Lora Gateway konektatzeko programa

Programa hau erabiltzen dugu gure lora esp32 mezuak bidaltzeko gure gateway-eri, eta horrela ikusi ahal dugu gure dispositiboaren mezuak gateway aplikazioan.

#include <lmic.h>

#include <hal/hal.h>

#include <SPI.h>

// LoRaWAN NwkSKey, network session key
// This is the default Semtech key, which is used by the early prototype TTN
// network.
static const PROGMEM u1_t NWKSKEY[16] = { 0x0E, 0x47, 0xF6, 0x3E, 0xF4, 0x6E, 0x65, 0x07, 0x9B, 0x41, 0x20, 0x16, 0x69, 0x2C, 0x09, 0xBD };
// LoRaWAN AppSKey, application session key
// This is the default Semtech key, which is used by the early prototype TTN
// network.
static const u1_t PROGMEM APPSKEY[16] = { 0x1B, 0x54 , 0x8E, 0xAC, 0x66, 0x0F, 0x32, 0x0A, 0xAB, 0x21, 0x09, 0x04, 0x46, 0x1C, 0x08, 0x6A };
// LoRaWAN end-device address (DevAddr)
static const u4_t DEVADDR = 0x26011E4D ; // <-- Change this address for every node! // These callbacks are only used in over-the-air activation, so they are
// left empty here (we cannot leave them out completely unless
// DISABLE_JOIN is set in config.h, otherwise the linker will complain).
void os_getArtEui (u1_t* buf) { }
void os_getDevEui (u1_t* buf) { }
void os_getDevKey (u1_t* buf) { }
static uint8_t mydata[] = "Hello, world!";
static osjob_t sendjob;
// Schedule TX every this many seconds (might become longer due to duty // cycle limitations).
const unsigned TX_INTERVAL = 60;
// Pin mapping
const lmic_pinmap lmic_pins = { .nss = 18,
.rxtx = LMIC_UNUSED_PIN,
.rst = 14,
.dio = {26, 33, 32},
};
void onEvent (ev_t ev) {
Serial.print(os_getTime()); Serial.print(": ");
switch(ev) {
case EV_SCAN_TIMEOUT:
Serial.println(F("EV_SCAN_TIMEOUT")); break;
case EV_BEACON_FOUND:
Serial.println(F("EV_BEACON_FOUND")); break;
case EV_BEACON_MISSED:
Serial.println(F("EV_BEACON_MISSED")); break;
case EV_BEACON_TRACKED:
Serial.println(F("EV_BEACON_TRACKED")); break;
case EV_JOINING:
Serial.println(F("EV_JOINING")); break;
case EV_JOINED:
Serial.println(F("EV_JOINED"));
19. orrialdea

break;
case EV_RFU1:
Serial.println(F("EV_RFU1")); break;
case EV_JOIN_FAILED:
Serial.println(F("EV_JOIN_FAILED")); break;
case EV_REJOIN_FAILED:
Serial.println(F("EV_REJOIN_FAILED"));
break;
case EV_TXCOMPLETE:
Serial.println(F("EV_TXCOMPLETE (includes waiting for RX windows)")); if (LMIC.txrxFlags & TXRX_ACK)
Serial.println(F("Received ack"));
if (LMIC.dataLen) {
Serial.println(F("Received ")); Serial.println(LMIC.dataLen); Serial.println(F(" bytes of payload"));
}
// Schedule next transmission
os_setTimedCallback(&sendjob, os_getTime()+sec2osticks(TX_INTERVAL), do_send);
break;
case EV_LOST_TSYNC:
Serial.println(F("EV_LOST_TSYNC")); break;
case EV_RESET:
Serial.println(F("EV_RESET")); break;
case EV_RXCOMPLETE:
// data received in ping slot Serial.println(F("EV_RXCOMPLETE")); break;
case EV_LINK_DEAD:
Serial.println(F("EV_LINK_DEAD")); break;
case EV_LINK_ALIVE:
Serial.println(F("EV_LINK_ALIVE")); break;
default:
Serial.println(F("Unknown event")); break;
}
}
void do_send(osjob_t* j){
// Check if there is not a current TX/RX job running if (LMIC.opmode & OP_TXRXPEND) {
Serial.println(F("OP_TXRXPEND, not sending"));
} else {
// Prepare upstream data transmission at the next possible time. LMIC_setTxData2(1, mydata, sizeof(mydata)-1, 0); Serial.println(F("Packet queued"));
}
// Next TX is scheduled after TX_COMPLETE event.
}

void setup() {
Serial.begin(115200);
Serial.println(F("Starting")); #ifdef VCC_ENABLE
// For Pinoccio Scout boards pinMode(VCC_ENABLE, OUTPUT); digitalWrite(VCC_ENABLE, HIGH); delay(1000);
20. orrialdea

#endif

// LMIC init
os_init();
// Reset the MAC state. Session and pending data transfers will be discarded. LMIC_reset();
// Set static session parameters. Instead of dynamically establishing a session // by joining the network, precomputed session parameters are be provided. #ifdef PROGMEM
// On AVR, these values are stored in flash and only copied to RAM
// once. Copy them to a temporary buffer here, LMIC_setSession will
// copy them into a buffer of its own again.
uint8_t appskey[sizeof(APPSKEY)];
uint8_t nwkskey[sizeof(NWKSKEY)];
memcpy_P(appskey, APPSKEY, sizeof(APPSKEY)); memcpy_P(nwkskey, NWKSKEY, sizeof(NWKSKEY));
LMIC_setSession (0x1, DEVADDR, nwkskey, appskey);
#else

// If not running an AVR with PROGMEM, just use the arrays directly LMIC_setSession (0x1, DEVADDR, NWKSKEY, APPSKEY);
#endif

#if defined(CFG_eu868)

// Set up the channels used by the Things Network, which corresponds // to the defaults of most gateways. Without this, only three base // channels from the LoRaWAN specification are used, which certainly // works, so it is good for debugging, but can overload those
// frequencies, so be sure to configure the full frequency range of // your network here (unless your network autoconfigures them).
// Setting up channels should happen after LMIC_setSession, as that
// configures the minimal channel set.
// NA-US channels 0-71 are configured automatically
LMIC_setupChannel(0, 868100000, DR_RANGE_MAP(DR_SF12, DR_SF7), BAND_CENTI); // g-band
LMIC_setupChannel(1, 868300000, DR_RANGE_MAP(DR_SF12, DR_SF7B), BAND_CENTI); // g-band
LMIC_setupChannel(2, 868500000, DR_RANGE_MAP(DR_SF12, DR_SF7), BAND_CENTI); // g-band
LMIC_setupChannel(3, 867100000, DR_RANGE_MAP(DR_SF12, DR_SF7), BAND_CENTI); // g-band
LMIC_setupChannel(4, 867300000, DR_RANGE_MAP(DR_SF12, DR_SF7), BAND_CENTI); // g-band
LMIC_setupChannel(5, 867500000, DR_RANGE_MAP(DR_SF12, DR_SF7), BAND_CENTI); // g-band
LMIC_setupChannel(6, 867700000, DR_RANGE_MAP(DR_SF12, DR_SF7), BAND_CENTI); // g-band
LMIC_setupChannel(7, 867900000, DR_RANGE_MAP(DR_SF12, DR_SF7), BAND_CENTI); // g-band
LMIC_setupChannel(8, 868800000, DR_RANGE_MAP(DR_FSK, DR_FSK), BAND_MILLI); // g2-band
// TTN defines an additional channel at 869.525Mhz using SF9 for class B // devices' ping slots. LMIC does not have an easy way to define set this // frequency and support for class B is spotty and untested, so this
// frequency is not configured here.
#elif defined(CFG_us915)

// NA-US channels 0-71 are configured automatically
// but only one group of 8 should (a subband) should be active
// TTN recommends the second sub band, 1 in a zero based count.
// https://github.com/TheThingsNetwork/gateway-conf/blob/master/US-global_conf.jsonLMIC_selectSubBand(1);
#endif

// Disable link check validation
LMIC_setLinkCheckMode(0);
// TTN uses SF9 for its RX2 window. LMIC.dn2Dr = DR_SF9;
21. orrialdea

// Set data rate and transmit power for uplink (note: txpow seems to be ignored by the library)
LMIC_setDrTxpow(DR_SF7,14);
// Start job
do_send(&sendjob);
}
void loop() {
os_runloop_once();
}

# 4.5 Lora neopixelarekin erabili

Lehenik eta behin neopixela arduino nano batekin konprobatu dogu ea ondo dabilela.

Hemen daukagu deskargatu beha diren librería eta informazioa. https://github.com/adafruit/Adafruit_NeoPixel

https://www.youtube.com/watch?v=gJm11ME-Un8

// NeoPixel Ring simple sketch (c) 2013 Shae Erisson
// Released under the GPLv3 license to match the rest of the // Adafruit NeoPixel library

#include <Adafruit_NeoPixel.h>

#ifdef __AVR__

#include <avr/power.h> // Required for 16 MHz Adafruit Trinket

#endif

// Which pin on the Arduino is connected to the NeoPixels?
#define PIN | 13 // On Trinket or Gemma, suggest changing this to 1

// How many NeoPixels are attached to the Arduino?
#define NUMPIXELS 8 // Popular NeoPixel ring size

// When setting up the NeoPixel library, we tell it how many pixels, // and which pin to use to send signals. Note that for older NeoPixel // strips you might need to change the third parameter -- see the
// strandtest example for more information on possible values. Adafruit_NeoPixel pixels(NUMPIXELS, PIN, NEO_GRB + NEO_KHZ800);

#define DELAYVAL 100 // Time (in milliseconds) to pause between pixels

void setup() {
// These lines are specifically to support the Adafruit Trinket 5V 16 MHz. // Any other board, you can remove this part (but no harm leaving it): #if defined(__AVR_ATtiny85__) && (F_CPU == 16000000) clock_prescale_set(clock_div_1);
#endif

// END of Trinket-specific code.

pixels.begin(); // INITIALIZE NeoPixel strip object (REQUIRED) }

void loop() {
pixels.clear(); // Set all pixel colors to 'off'

// The first NeoPixel in a strand is #0, second is 1, all the way up // to the count of pixels minus one.
for(int i=0; i<8; i++) { // For each pixel...

// pixels.Color() takes RGB values, from 0,0,0 up to 255,255,255

22. orrialdea

// Here we're using a moderately bright green color: pixels.setPixelColor(i, pixels.Color(50, 0, 0));

pixels.show(); // Send the updated pixel colors to the hardware.

delay(DELAYVAL); // Pause before next pass through loop
}
}

# 1.1 Tenperatura eta hezetasuna sentsorea

# 4.5.1 Sarrera

DHT11 tenperatura eta hezetasun digitaleko sentsore bat da, kostu txikikoa. Hezetasun-sentsore kapazitibo bat eta termistor bat erabiltzen ditu inguruko airea neurtzeko, eta datuak seinale digital baten bidez erakusten ditu datu-pinuan (ez dago sarrerako pinu analogikorik).


- Operazio-tentsioa:3V-5VDC.
- Tenperatura neurtzeko tartea: 0 eta 50 ° C bitartean.
- Tenperatura neurtzeko doitasuna: ± 2.0 ° c
- Denbora-ebazpena: 0.1 ° C.
- Hezetasuna neurtzeko tartea:% 20tik % 90era Rh.
- Hezetasuna neurtzeko zehaztasuna:% 5 Rh.
- Hezetasunaren ebazpena: Rh% 1. Sensida-denbora: 1 seg.
23. orrialdea


https://www.mouser.com/datasheet/2/758/DHT11-Technical-Data-Sheet-Translated-Version-1143054.pdf

https://www.mouser.com/datasheet/2/758/DHT11-Technical-Data-Sheet-Translated-Version-1143054.pdf

# 4.5.2 Eskema elektronikoak

# 4.5.3 Sentsorearen edo shieldaren pinout-a

Sentsore hau funtzionatzeko erresitentzia bat erabili
behar dugu. Erresistentzia pull up moduan jarriko dugu.

Behar dugun libreria isntalatu. https://github.com/adafruit/Adafruit_Sensor

https://github.com/adafruit/DHT-sensor-library

/*
Programaren izena: DHTtester_JON_MIKEL
24. orrialdea

Egilea: JON eta MIKEL Data: 22/02/2021
Zeregina: DHT sentsorearekin tenperatura eta hezetazuna neurtzea. Adibide hau domeinu publikokoa da.
Programaren egoera: Egiaztatzeko/Egiaztatuta
Egiaztatutako plakak: hasiera batean Nano-arekin konprobatu dugu.
*/
/*-----( LIBURUTEGIAK )----*/
// - DHT Sensor Library: https://github.com/adafruit/DHT-sensor-library
// - Adafruit Unified Sensor Lib: https://github.com/adafruit/Adafruit_Sensor #include <DHT.h>
#include <DHT_U.h>

#include "DHT.h"

#define DHTPIN 2 // DHT sentsoreari lotutako Digital pin

//Erabili pinak 3, 4, 5, 12, 13 edo 14.
//Pin 15ek funtziona dezake, baina DHT deskonektatu egin behar da programazioan.

/*-----( KONSTANTEAK )-----*/
#define DHTTYPE DHT11 | // DHT 11

//#define DHTTYPE DHT22 | // DHT 22 (AM2302), AM2321
//#define DHTTYPE DHT21 | // DHT 21 (AM2301)

// Connect pin 1 (ezkerrean) of the sensor to +5V
//3.3V logika duen taula bat Arduino Due batek pin 1 konektatzen badu //5V ordez, 3.3V!
//Zure DHTPIN DOKTOREARI
//X/Connect pin 4 (eskuinaldean)
//Connect a 10K resistor from pin 2 (datuak) to pin 1 (boterea)

//DHT sentsorea.
//Liburutegi honen bertsio zaharragoek hirugarren parametro bat eraman zuten. //Parametro hau ez da beharrezkoa prozesadore azkarragoentzat.
//DHT irakurgailuaren algoritmoa prozesu azkarragoetan lan egitera egokitzen da. //DHT dht(DHTPIN, DHTTYPE);

void setup() {
Serial.begin(9600);
Serial.println(F("DHTxx test!"));

dht.begin();
}

void loop() {
// Wait a few seconds between measurements.
delay(2000);

// Reading temperature or humidity takes about 250 milliseconds!
// Sensor readings may also be up to 2 seconds 'old' (its a very slow sensor) float h = dht.readHumidity();
// Read temperature as Celsius (the default)
float t = dht.readTemperature();
// Read temperature as Fahrenheit (isFahrenheit = true) float f = dht.readTemperature(true);

// Check if any reads failed and exit early (to try again). if (isnan(h) || isnan(t) || isnan(f)) { Serial.println(F("Failed to read from DHT sensor!")); return;
}

// Compute heat index in Fahrenheit (the default) float hif = dht.computeHeatIndex(f, h);
// Compute heat index in Celsius (isFahreheit = false) float hic = dht.computeHeatIndex(t, h, false);
25. orrialdea

Serial.print(F("hezetasuna: ")); Serial.print(h);
Serial.print(F("% Temperatura: ")); Serial.print(t);
Serial.print(F("°C "));
Serial.print(f);
Serial.print(F("°F Bero-indizea: ")); Serial.print(hic);
Serial.print(F("°C "));
Serial.print(hif);
Serial.println(F("°F"));

}

4.5.5 Oinarrizko programa funtzioak bihurtuta; * Bueltatzen duena: ezer * Sartutako parametroak:; int; * * */ void DTH11sentsoreaSETUP (void){ Serial.println(F("DHTxx test!"));

/* Funtzioa: int DTH11sentsorea (int zeinPin)
* Zeregina: DTH11 sentsorean temperatura eeta hezetasuna naurtzen du.
* Erabilitako liburutegiak: DTH11DHT Sensor Library eta Adafruit
* Liburutegia nondik hartuta: https://github.com/adafruit/Adafruit_Sensor // https://github.com/adafruit/DHT-sensor-library

dht.begin();
}

/* Funtzioa: int DTH11sentsorea (int zeinPin)
* Zeregina: DTH11 sentsorean temperatura eeta hezetasuna naurtzen du.
* Erabilitako liburutegiak: DTH11DHT Sensor Library eta Adafruit
* Liburutegia nondik hartuta: https://github.com/adafruit/Adafruit_Sensor // https://github.com/adafruit/DHT-sensor-library
* Bueltatzen duena: ezer
* Sartutako parametroak:
* int
*
* */
void DTH11sentsoreaLOOP (void){
| // Wait a few seconds between measurements. delay(2000);
| // Reading temperature or humidity takes about 250 milliseconds! // Sensor readings may also be up to 2 seconds 'old' (its a very slow sensor) float h = dht.readHumidity(); // Read temperature as Celsius (the default) float t = dht.readTemperature(); // Read temperature as Fahrenheit (isFahrenheit = true) float f = dht.readTemperature(true);
26. orrialdea

// Check if any reads failed and exit early (to try again). if (isnan(h) || isnan(t) || isnan(f)) { Serial.println(F("Failed to read from DHT sensor!")); return;
}

// Compute heat index in Fahrenheit (the default) float hif = dht.computeHeatIndex(f, h);
// Compute heat index in Celsius (isFahreheit = false) float hic = dht.computeHeatIndex(t, h, false);

Serial.print(F("hezetasuna: "));
Serial.print(h);
Serial.print(F("% Temperatura: ")); Serial.print(t);
Serial.print(F("°C "));
Serial.print(f);
Serial.print(F("°F Bero-indizea: ")); Serial.print(hic);
Serial.print(F("°C "));
Serial.print(hif);
Serial.println(F("°F"));
}

# 4.5.6 Material zerrenda

Izena | Kopurua | Oharrak edota ezaugarri bereziak
DHT11 | 1 | Errezistentzia erabilitzen dugu. (PULL UP)
ARDUINO NANO | 1 | Sentsorea probetako erabiltzen dugu.

# 4.5.7 Gorabeherak

# 4.5.8 Estekak

https://steve.fi/hardware/temperature/

https://www.zonamaker.com/electronica/intro-electronica/teoria/resistencias-de-pull-up-y-pull-down

https://forum.fritzing.org/t/heltec-dev-boards/8112

https://fritzing.org/projects/dht11-temp-and-humidity-sensor

27. orrialdea

# 4.6 CO2 sentsorea

# 4.6.1 Sarrera

CCS811 sentsore bat da barneko airearen kalitatea neurtzeko, eta erraz erabil dezakegu Arduino bezalako prozesadore batekin batera.
Barneko airearen kalitatea zehazteko, CCS811 MOX (Metal-Oxide) sentsore multigas bat da, karbono monoxidoa (Co) eta konposatu lurrunkorrak (VOCs) neurtzea barne hartzen duena, hala nola etanola, aminak edo hidrokarburo aromatikoak. Horien bidez, CCS811k karbono dioxido baliokidearen (eCO2) kantitatea zehaztu dezake. Neurketa-tartea 400 eta 8192 ppm artekoa da eCO2-n eta 0 eta 1187 ppb artekoa TVOCen.


- Konposatu organiko lurrunkorra guztira (TVOC), milioi bakoitzeko 0 eta 1187 zati bitartean detektatzen dituena
- ECO2ren detekzioa, 400etik 8,192ra milioiko.
- Bost funtzionamendu-modu
- MCU integratua
- I2C interfaze digital estandarra
- Kontsumo txikiko moduak
- Elikadura: 3.3V a 5V
- Neurriak: 21 x 18 x 3 milimetro
- Pisua: 1.2 gramo

Datasheet-ak ez du neurketaren zehaztasunari buruzko daturik ematen.

https://cdn.sparkfun.com/assets/2/c/c/6/5/CN04-2019_attachment_CCS811_Datasheet_v1-06.pdf

28. orrialdea

# 4.6.2 Eskema elektronikoak


29. orrialdea

# 4.6.3 Sentsorearen edo shieldaren pinout-a

4.6.4 Oinarrizko programa; /* Programaren izena: DHTtester_JON_MIKEL

Behar dugun lebreria istalatu. //https://github.com/adafruit/Adafruit_CCS811

Egilea: JON eta MIKEL Data: 22/02/2021
Zeregina: DHT sentsorearekin tenperatura eta hezetazuna neurtzea. Adibide hau domeinu publikokoa da.
Programaren egoera: Egiaztatzeko/Egiaztatuta
Egiaztatutako plakak: hasiera batean Nano-arekin konprobatu dugu.
*/
/*-----( LIBURUTEGIAK )----*/
#include "Adafruit_CCS811.h" //https://github.com/adafruit/Adafruit_CCS811

Adafruit_CCS811 ccs;

void setup() {
Serial.begin(9600);

Serial.println("CCS811 test");

if(!ccs.begin()){
Serial.println("Failed to start sensor! Please check your wiring."); while(1);
}

// Wait for the sensor to be ready
while(!ccs.available());
}

void loop() {
if(ccs.available()){
if(!ccs.readData()){
//Serial.println(ccs.calculateTemperature()); Serial.print("ºC, CO2: "); Serial.print(ccs.geteCO2());
30. orrialdea

Serial.print("ppm, TVOC: "); Serial.println(ccs.getTVOC()); }
else{
Serial.println("ERROR!");
while(1);
}
}
delay(500);
}


# 4.6.5 Oinarrizko programa funtzioak bihurtuta

/* Funtzioa: void CO2sentsorea (void)
* Zeregina:CO2 sentsorean naurtzea du.
* Erabilitako liburutegiak: DTH11DHT Sensor Library eta Adafruit
* Liburutegia nondik hartuta://https://github.com/adafruit/Adafruit_CCS811 * Bueltatzen duena: ezer
* Sartutako parametroak:
* int
*
31. orrialdea

* */
void CO2sentsoreaSETUP (void){

Serial.println("CCS811 test");

if(!ccs.begin()){
Serial.println("Failed to start sensor! Please check your wiring."); while(1);
}

// Wait for the sensor to be ready
while(!ccs.available());
}

/* Funtzioa: void CO2sentsorea (void)
* Zeregina:CO2 sentsorean naurtzea du.
* Erabilitako liburutegiak: DTH11DHT Sensor Library eta Adafruit
* Liburutegia nondik hartuta://https://github.com/adafruit/Adafruit_CCS811 * Bueltatzen duena: ezer
* Sartutako parametroak:
* int
*
* */
void CO2sentsoreaLOOP (void){
| if(ccs.available()){ if(!ccs.readData()){ //Serial.println(ccs.calculateTemperature()); Serial.print("CO2: "); Serial.print(ccs.geteCO2()); Serial.println("ppm"); Serial.print("TVOC: "); Serial.println(ccs.getTVOC());

}
| else{ Serial.println("ERROR!"); while(1);

}
}
| delay(500);
}

# 4.6.6 Material zerrenda

Izena | Kopurua | Oharrak edota ezaugarri bereziak
CO2 (Sentsorea) | 1
ARDUINO NANO | 1 | Sentsorea probetako erabiltzen dugu.

# 4.6.7 Gorabeherak

# 4.6.8 Estekak

https://www.luisllamas.es/medir-calidad-del-aire-y-co2-con-ccs811-y-arduino/

32. orrialdea https://tienda.bricogeek.com/sensores-gas/1508-sensor-de-calidad-del-aire-ccs811-voc-y-co2.html

http://digitalconcepts.net.au/fritzing/index.php?op=parts

33. orrialdea

# 5 Arduino nano pinen esleipena

## 1.8. ESP-32 hardware eta software baliabideak

DIGITALA | KOMUNIKAZIOAK | GAINERAKOA K | ERABILERA

GPI0/GPO0

GPI1/GPO1 | UART TxD | | Ordenagailuarekin komunikatzeko (Serial) Datuak bidali

GPI2/GPO2

GPI3/GPO3 | UART RxD | | Ordenagailuarekin komunikatzeko (Serial) Datuak jaso
GPI4/GPO4 | SDA | | OLED_SDA ETA CJMCU-811 (CO2_Sentsorea)
GPI5/GPO5 | SPI CSO | | LORA_SCK ETA CJMCU-811 (CO2_Sentsorea)

GPI12/GPO12

GPI13/GPO13 | | | CJMCU-2812-8(Led Neopixel)
GPI14/GPO14 | | | LORA_RST
GPI15/GPO15 | SCL | | OLED_SCL
GPI16/GPO16 | U2 RXD | | OLED_RST
GPI17/GPO17 | U2 TXD | | DHT11 (Tenperatura eta Hezetasuna)

DIGITALA | KOMUNIKAZIOAK | GAINERAKOA K | ERABILERA
GPI18/GPO18 | SPI CLK | | LORA_CS
GPI19/GPO19 | | | LORA_MISO
GPI21/GPO21 | SDA | | CJMCU-811 (CO2_Sentsorea)
GPI22/GPO22 | SCL | | CJMCU-811 (CO2_Sentsorea)

GPI23/GPO23

GPI24/GPO24

GPI25/GPO25

GPI26/GPO26 | | | LORA_IRQ
GPI27/GPO27 | | | LORA_MOSI

GPI32/GPO32

GPI33/GPO33

GPI34/GPO34

GPI35/GPO35

DIGITALA | KOMUNIKAZIOAK | GAINERAKOA K | ERABILERA

GPI36/GPO36

GPI37/GPO37
GPI38/GPO38
GPI39/GPO39

38. orrialdea

# 6 GateWay konfigurazioa

GateWay bat LoRa transmisio modulua duen gailua da eta informazioa Internet eta berarekin komunikatzen diren nodoen artean birbidaltzen du eta alderantziz.

GateWay-a konfiguratzeko tutorial edo manual bat aurkitu dugu interneten.
Hainbat pasu segi ditugu, honako hauek:
- Lehenengo pausua, gure GateWay-a elikatu ondoren Reset botoia 5 segunduz pultsatzea da, goiko aldean duen LEDa azkar
parpadeatzen(berde-gorri) jarri arte
- Ondoren Setup botoia 10 segunduz pultsauta

erakusten du, SSID MINIHUB-xxxxxx dena,; ikus dezakegu.

mantendu LEDa gorriz parpadeatzen jarri harte.

- Hau lortu eta gero GateWay-a orain WiFi AP bat

non xxxxxx GateWay-aren IDA da, 6 digito.

- GateWay-aren pasahitza gailuaren atzeko aldean
39. orrialdea

- Azkenik, 192.168.4.1 sarrera sartu eta hor Wifia aukeratu duguKonfigurazioa zuzena bada, Gateway-a berdez kliskatuko du segundo batzuetan, sare horretara konektatzen den bitartean.
- Konfigurazioa zuzena bada, pasabideak BERDE < ->GORRIAN kliskatuko du segundo batzuetan, CUPS azken puntura konektatzen den bitartean, eta LNS trafikoko azken puntura konektatzeko beharrezkoa den informazioa lortzen du.

Konfigurazioa zuzena izan bada, Led berde finkoan egongo da, eta horrek esan nahi du GateWay-a konektatuta dagoela.

40. orrialdea

# 7 Elikatze iturria (Hi link)

## Sarrera

Serieko elikadura-modulu ultra-txikia Potentzia ultra txikikoa, serieko hornidura-modulu txikia, 3W bolumen txiki bat da, elikadura-efizientzia handia, Shenzhen Hola-Link Electronics Co, Ltd enpresak diseinatua. Abantaila hauek ditu: sarrera globaleko tentsio-tartea, tenperatura-igoera txikia, energia-kontsumo txikia, eraginkortasun handia, fidagarritasun handia eta segurtasun-isolamendu handia. Asko erabili da etxe adimendunetan, automatizazio-kontrolean, komunikazio-ekipoetan, tresnerian eta beste industria batzuetan.

## Ezaugarriak


- Sarrerako tentsio nominala: 100-240 VCA
- Sarrerako tentsio-maila: 90-264 VCA
- Gehieneko sarrera-boltajea: 270 Vac
- Gehieneko sarrera-korrontea: 0.2tik
- Sarrerako gainjarpena: 10-a
- Hasiera motela: 50 ms
- Tentsio txikiko sarrera-eraginkortasuna: vin = 110 VCA Irteera osoa,% 69ko irteerako irteera osoa

## Estekak

https://datasheetspdf.com/datasheet/HLK-PM01.html

41. orrialdea

# 8 Egindako kalkulu guztiak

# 8.1 Elikatze-iturriaren kalkuluak

Gure osagai guztiak zenbateko elikadura behar dituen eta zenbat mA erabiltzen dituen. Taula honetan adierazten dugu.

PLAKAKO ELIKADURA | KANPOKO ELIKADURA | ERABILERA
VI N | 5V | 3V3 | GND | RESE T | V | mA
| | X | | | 3V3 | 20mA | TT-GO-ESP32
| | X | | | | 4.5mA | CCS811 (CO2 Sentsorea)
| | X | | | | 2.5mA | DHT11 (Tenperatura eta Hezetasuna Sentsorea)
| | X | | | | 900mA | Neopixel
12 voltio | | | | | 220 | 1100%20220mA | Bateria DC
42. orrialdea

# 9 Eskema elektrikoak

## Kicad Eskema:


## Fritzing eskemak

LORA esp 32 eta DHT11 protoboard.

LORA esp 32 eta CCS811 protoboard.

43. orrialdea

44. orrialdea

LORA esp 32 ,CCS811 eta DHT11 protoboard.

45. orrialdea

LORA esp 32 ,CCS811, DHT11 eta NEOPIXEL protoboard.


# Material zerrenda

Erronka osoan erabiliko dugun material oso a.

Izena | Kopurua | Oharrak edota ezaugarri bereziak
DHT-11 | 1 | 3 pin
CO2 sentsorea | 1
Neopixel | 1x8
Elikatze iturria DC | 1
ESP32 kontrolagailua | 1 | Nodo
46. orrialdea

# 10 10.Gorabeherak

- LORA ESP32-ko oled pantaila, ez dut lortzen beti datuak agertzea. Uste dut plakaren arazoa dela bai golperenbat hartu duelako, bai txarto soldeatuta dagoelako … batzutan funtzionatzen du eta beste batzutan ez. Programa berdinarekin probatzen dugu.
- Lehenengo PCB placa txarto fresatuta, pin asko nahasiak eta orain ez doa ezer. Osagai batenbat apurtuta egon ahal da.
47. orrialdea

48. orrialdea

# 11 PROGRAMA NAGUSIA

## Sentsoren bidalketa:

/*
Programaren izena: DHTtester_JON_MIKEL
Egilea: JON eta MIKEL Data: 22/02/2021
Zeregina: DHT sentsorearekin tenperatura eta hezetazuna neurtzea. Adibide hau domeinu publikokoa da.
Programaren egoera: Egiaztatzeko/Egiaztatuta
Egiaztatutako plakak: hasiera batean Nano-arekin konprobatu dugu. */

#include "LoraGatewayHeader.h"

void setup() {
Serial.begin(115200);
DTH11sentsoreaSETUP ();
OledPantallaSETUP();
CO2sentsoreaSETUP ();
tntSETUP ();
NeopixelSETUP();

}

void loop() {
DTH11sentsoreaLOOP ();
OledPantallaLOOP ();
CO2sentsoreaLOOP ();
tntLOOP ();
NeopixelLOOP ();
}

## Bidalketa:

/* Funtzioa: void CO2sentsorea (void)
* Zeregina: ditugun datuak tnt-ra bidaltzea * Erabilitako liburutegiak:
* Liburutegia nondik hartuta:
* Bueltatzen duena: ezer
* Sartutako parametroak:
*
*
* */
void BidalketaLOOP (void){

float h = dht.readHumidity();
// Read temperature as Celsius (the default)
float t = dht.readTemperature();

unsigned long balioa =((t*10000000)+(h*10000)+(ccs.geteCO2())); //bidaliko dugun zenbakizko txurroaren simulazioa, balioa adibide bat da TTTHHCCCC
String payload = String(balioa); | //txurroa string
batera pasatu
static uint8_t payloadChar[10]; | //karaktereen arraya
sortu
payload.toCharArray((char *)payloadChar, sizeof(payloadChar)); //stringa char array bihurtu
49. orrialdea

// Prepare upstream data transmission at the next possible time. Bidalketa egiteko lekua, payloadChar aldagaia bidaltzen du
LMIC_setTxData2(1, payloadChar, sizeof(payloadChar)-1, 0); Serial.println(F("Packet queued"));
}

## CO2 sentsorea

/* Funtzioa: void CO2sentsorea (void)
* Zeregina:CO2 sentsorean naurtzea du.
* Erabilitako liburutegiak: DTH11DHT Sensor Library eta Adafruit
* Liburutegia nondik hartuta://https://github.com/adafruit/Adafruit_CCS811 * Bueltatzen duena: ezer
* Sartutako parametroak:
* int
*
* */
void CO2sentsoreaSETUP (void){
| Serial.println("CCS811 test");
| if(!ccs.begin()){ Serial.println("Failed to start sensor! Please check your wiring."); while(1);

}

| // Wait for the sensor to be ready while(!ccs.available());

}

/* Funtzioa: void CO2sentsorea (void)
* Zeregina:CO2 sentsorean naurtzea du.
* Erabilitako liburutegiak: DTH11DHT Sensor Library eta Adafruit
* Liburutegia nondik hartuta://https://github.com/adafruit/Adafruit_CCS811 * Bueltatzen duena: ezer
* Sartutako parametroak:
* int
*
* */
void CO2sentsoreaLOOP (void){
| if(ccs.available()){ if(!ccs.readData()){ //Serial.println(ccs.calculateTemperature()); Serial.print("CO2: "); Serial.print(ccs.geteCO2()); Serial.println("ppm"); Serial.print("TVOC: "); Serial.println(ccs.getTVOC());

}
| else{ Serial.println("ERROR!"); while(1);

}
}
| delay(1000);
}
50. orrialdea

## DTH11 sentsorea:

/* Funtzioa: int DTH11sentsorea (int zeinPin)
* Zeregina: DTH11 sentsorean temperatura eeta hezetasuna naurtzen du.
* Erabilitako liburutegiak: DTH11DHT Sensor Library eta Adafruit
* Liburutegia nondik hartuta: https://github.com/adafruit/Adafruit_Sensor // https://github.com/adafruit/DHT-sensor-library
* Bueltatzen duena: ezer
* Sartutako parametroak:
* int
*
* */
void DTH11sentsoreaSETUP (void){
| Serial.println(F("DHTxx test!"));
| dht.begin();
}

/* Funtzioa: int DTH11sentsorea (int zeinPin)
* Zeregina: DTH11 sentsorean temperatura eeta hezetasuna naurtzen du.
* Erabilitako liburutegiak: DTH11DHT Sensor Library eta Adafruit
* Liburutegia nondik hartuta: https://github.com/adafruit/Adafruit_Sensor // https://github.com/adafruit/DHT-sensor-library
* Bueltatzen duena: ezer
* Sartutako parametroak:
* int
*
* */
void DTH11sentsoreaLOOP (void){
| // Wait a few seconds between measurements. delay(1000);
| // Reading temperature or humidity takes about 250 milliseconds! // Sensor readings may also be up to 2 seconds 'old' (its a very slow sensor) float h = dht.readHumidity(); // Read temperature as Celsius (the default) float t = dht.readTemperature(); // Read temperature as Fahrenheit (isFahrenheit = true) float f = dht.readTemperature(true);
| // Check if any reads failed and exit early (to try again). if (isnan(h) || isnan(t) || isnan(f)) { Serial.println(F("Failed to read from DHT sensor!")); return;

}

| // Compute heat index in Fahrenheit (the default) float hif = dht.computeHeatIndex(f, h); // Compute heat index in Celsius (isFahreheit = false) float hic = dht.computeHeatIndex(t, h, false);
| Serial.print(F("hezetasuna: ")); Serial.print(h); Serial.print(F("% Temperatura: ")); Serial.print(t); Serial.print(F("°C ")); Serial.print(f); Serial.print(F("°F Bero-indizea: ")); Serial.print(hic); Serial.print(F("°C ")); Serial.print(hif);
51. orrialdea

Serial.println(F("°F"));
}

## Lora gateway:

/*-----( LIBURUTEGIAK )----*/
// - DHT Sensor Library: https://github.com/adafruit/DHT-sensor-library
// - Adafruit Unified Sensor Lib: https://github.com/adafruit/Adafruit_Sensor//#include <DHT.h>
//#include <DHT_U.h>
#include "DHT.h"

#define DHTPIN 17 // DHT sentsoreari lotutako Digital pin

#include "Adafruit_CCS811.h" //https://github.com/adafruit/Adafruit_CCS811

#include <lmic.h>

#include <hal/hal.h>

#include <SPI.h>

//Libraries for LoRa
#include <LoRa.h>

//Libraries for OLED Display #include <Wire.h>
#include <Adafruit_GFX.h>

#include <Adafruit_SSD1306.h>

#include <Adafruit_NeoPixel.h>

#ifdef __AVR__

#include <avr/power.h> // Required for 16 MHz Adafruit Trinket #endif

/*-----( KONSTANTEAK )-----*/
#define DHTTYPE DHT11 | // DHT 11

//#define DHTTYPE DHT22 | // DHT 22 (AM2302), AM2321
//#define DHTTYPE DHT21 | // DHT 21 (AM2301)
//define the pins used by the LoRa transceiver module #define SCK 5
#define MISO 19

#define MOSI 27

#define SS 18

#define RST 14

#define DIO0 26

//433E6 for Asia
//866E6 for Europe
//915E6 for North America
#define BAND 866E6

//OLED pins
#define OLED_SDA 4

#define OLED_SCL 15

#define OLED_RST 16

#define SCREEN_WIDTH 128 // OLED display width, in pixels

#define SCREEN_HEIGHT 64 // OLED display height, in pixels

#define DELAYVAL 100 // Time (in milliseconds) to pause between pixels

// Which pin on the Arduino is connected to the NeoPixels?
#define PIN | 13 // On Trinket or Gemma, suggest changing this to 1

// How many NeoPixels are attached to the Arduino?
#define NUMPIXELS 8 // Popular NeoPixel ring size

/*-----( OBJETUAK )-----*/
DHT dht(DHTPIN, DHTTYPE);
Adafruit_CCS811 ccs;
Adafruit_SSD1306 display(SCREEN_WIDTH, SCREEN_HEIGHT, &Wire, OLED_RST);
52. orrialdea

String LoRaData;
Adafruit_NeoPixel pixels(NUMPIXELS, PIN, NEO_GRB + NEO_KHZ800);
static const PROGMEM u1_t NWKSKEY[16] = { 0x0E, 0x47, 0xF6, 0x3E, 0xF4, 0x6E, 0x65, 0x07, 0x9B, 0x41, 0x20, 0x16, 0x69, 0x2C, 0x09, 0xBD };

static const u1_t PROGMEM APPSKEY[16] = { 0x1B, 0x54 , 0x8E, 0xAC, 0x66, 0x0F, 0x32, 0x0A, 0xAB, 0x21, 0x09, 0x04, 0x46, 0x1C, 0x08, 0x6A };

static const u4_t DEVADDR = 0x26011E4D ; // <-- Change this address for every node! /*-----( FUNTZIOAK )-----*/
void CO2sentsoreaSETUP (void);
void CO2sentsoreaLOOP (void);
void DTH11sentsoreaSETUP (void); void DTH11sentsoreaLOOP (void); void tntSETUP (void);
void tntLOOP (void);
void OledPantallaSETUP (void); void OledPantallaLOOP (void); void NeopixelSETUP (void); void NeopixelLOOP (void);
//BIDALKETA
void BidalketaLOOP (void);
void os_getArtEui (u1_t* buf) { }
void os_getDevEui (u1_t* buf) { }
void os_getDevKey (u1_t* buf) { }

static uint8_t mydata[] = "Hello, world!"; static osjob_t sendjob;
const unsigned TX_INTERVAL = 18000;

// Pin mapping
const lmic_pinmap lmic_pins = { .nss = 18,
.rxtx = LMIC_UNUSED_PIN,
.rst = 14,
.dio = {26, 33, 32},
};

## Neopixel:

/* Funtzioa: void NeopixelSETUP (void)
* Zeregina: Neopixela eta bere argiak zehaztea. * Erabilitako liburutegiak:
* Liburutegia nondik hartuta:
* Bueltatzen duena: ezer
* Sartutako parametroak:
*
*
* */

void NeopixelSETUP (void)
{
// These lines are specifically to support the Adafruit Trinket 5V 16 MHz. // Any other board, you can remove this part (but no harm leaving it): #if defined(__AVR_ATtiny85__) && (F_CPU == 16000000) clock_prescale_set(clock_div_1);
#endif

// END of Trinket-specific code.

pixels.begin(); // INITIALIZE NeoPixel strip object (REQUIRED) }
/* Funtzioa: void NeopixelLOOP(void)
* Zeregina:
53. orrialdea

* Erabilitako liburutegiak:
* Liburutegia nondik hartuta: pin zehaztu * Bueltatzen duena: ezer
* Sartutako parametroak:
*
*
* */
void NeopixelLOOP(void)
{
pixels.clear(); // Set all pixel colors to 'off'

// The first NeoPixel in a strand is #0, second is 1, all the way up // to the count of pixels minus one.
//for(int i=0; i<8; i++) { // For each pixel...

//pixels.Color() takes RGB values, from 0,0,0 up to 255,255,255 // Here we're using a moderately bright green color:
// pixels.setPixelColor(0, pixels.Color(50, 80, 0));
// pixels.setPixelColor(1, pixels.Color(50, 0, 0));
// pixels.setPixelColor(2, pixels.Color(0, 50, 0)); // pixels.setPixelColor(3, pixels.Color(0, 0, 50)); // pixels.setPixelColor(4, pixels.Color(50, 50, 0)); // pixels.setPixelColor(5, pixels.Color(50, 0, 50)); // pixels.setPixelColor(6, pixels.Color(0, 50, 50)); //pixels.setPixelColor(7, pixels.Color(50, 50, 0));

if(!ccs.readData()){
//Serial.println(ccs.calculateTemperature()); Serial.print("CO2: ");
Serial.print(ccs.geteCO2()); Serial.println("ppm");
Serial.print("TVOC: ");
Serial.println(ccs.getTVOC()); }
else{
Serial.println("ERROR!");
while(1);
}

if (ccs.geteCO2()>=400 & ccs.geteCO2()<750){ pixels.setPixelColor(0, pixels.Color(0, 50, 0)); pixels.setPixelColor(1, pixels.Color(0, 50, 0)); pixels.setPixelColor(2, pixels.Color(0, 50, 0)); }
else {
if (ccs.geteCO2()>=750 & ccs.geteCO2()<1100){ pixels.setPixelColor(0, pixels.Color(0, 50, 0)); pixels.setPixelColor(1, pixels.Color(0, 50, 0)); pixels.setPixelColor(2, pixels.Color(0, 50, 0)); pixels.setPixelColor(3, pixels.Color(50, 50, 0)); pixels.setPixelColor(4, pixels.Color(50, 50, 0)); pixels.setPixelColor(5, pixels.Color(50, 50, 0)); }
else {
pixels.setPixelColor(0, pixels.Color(0, 50, 0)); pixels.setPixelColor(1, pixels.Color(0, 50, 0)); pixels.setPixelColor(2, pixels.Color(0, 50, 0)); pixels.setPixelColor(3, pixels.Color(50, 50, 0)); pixels.setPixelColor(4, pixels.Color(50, 50, 0)); pixels.setPixelColor(5, pixels.Color(50, 50, 0)); pixels.setPixelColor(6, pixels.Color(50, 0, 0)); pixels.setPixelColor(7, pixels.Color(50, 0, 0)); }
}
54. orrialdea pixels.show(); // Send the updated pixel colors to the hardware.

delay(DELAYVAL); // Pause before next pass through loop
}

## Oled pantaila:

/* Funtzioa: void OledPantallaSETUP (void){ * Zeregina: oled pantalla datuak agertzea * Erabilitako liburutegiak:
* Liburutegia nondik hartuta:
* Bueltatzen duena: ezer
* Sartutako parametroak:
*
*
* */
void OledPantallaSETUP (void){

//reset OLED display via software pinMode(OLED_RST, OUTPUT); digitalWrite(OLED_RST, LOW); delay(20);
digitalWrite(OLED_RST, HIGH);

//initialize OLED
Wire.begin(OLED_SDA, OLED_SCL);
if(!display.begin(SSD1306_SWITCHCAPVCC, 0x3c, false, false)) { // Address 0x3C for 128x32
Serial.println(F("SSD1306 allocation failed"));
for(;;); // Don't proceed, loop forever
}

display.clearDisplay();
display.setTextColor(WHITE); display.setTextSize(1);
display.setCursor(0,0);
display.print("Kargatzen..."); display.display();

//initialize Serial Monitor Serial.begin(115200);

Serial.println("LoRa Receiver Test");

//SPI LoRa pins
SPI.begin(SCK, MISO, MOSI, SS); //setup LoRa transceiver module LoRa.setPins(SS, RST, DIO0);

if (!LoRa.begin(BAND)) {
Serial.println("Starting LoRa failed!"); while (1);
}
Serial.println("LoRa Initializing OK!"); //display.setCursor(0,10); //display.println("LoRa Initializing OK!"); //display.display();
}
/* Funtzioa: void OledPantallaLOOP (void) { * Zeregina:
55. orrialdea

* Erabilitako liburutegiak: * Liburutegia nondik hartuta: * Bueltatzen duena: ezer
* Sartutako parametroak:
*
*
* */
void OledPantallaLOOP (void) {
float h = dht.readHumidity();
// Read temperature as Celsius (the default) float t = dht.readTemperature();

if(ccs.available()){
if(!ccs.readData()){
//Serial.println(ccs.calculateTemperature()); Serial.print("CO2: ");
Serial.print(ccs.geteCO2()); Serial.println("ppm");
Serial.print("TVOC: ");
Serial.println(ccs.getTVOC()); }
else{
Serial.println("ERROR!");
while(1);
}
}

// Dsiplay information
display.clearDisplay();
display.setCursor(0,0);
display.print("MIKEL_JON"); display.setCursor(0,20);
display.print("TenperaturaHezetasuna"); display.setCursor(0,30);
display.print(t);
display.setCursor(70,30);
display.print(h);
display.setCursor(0,40);
display.print("CO2_TVCO"); display.setCursor(0,50);
display.print(ccs.geteCO2()); display.setCursor(40,50);
display.print(ccs.getTVOC()); display.display();

}

## Ttn:

/* Funtzioa: onEvent (ev_t ev)
* Zeregina:
* Erabilitako liburutegiak: https://github.com/adafruit/Adafruit_Sensor * https://github.com/adafruit/DHT-sensor-library
* Liburutegia nondik hartuta: Internetetik
* Bueltatzen duena: ezer
* Sartutako parametroak:
* void
*
* */

void onEvent (ev_t ev) {

56. orrialdea

Serial.print(os_getTime()); Serial.print(": ");
switch(ev) {
case EV_SCAN_TIMEOUT:
Serial.println(F("EV_SCAN_TIMEOUT")); break;
case EV_BEACON_FOUND:
Serial.println(F("EV_BEACON_FOUND")); break;
case EV_BEACON_MISSED:
Serial.println(F("EV_BEACON_MISSED")); break;
case EV_BEACON_TRACKED:
Serial.println(F("EV_BEACON_TRACKED")); break;
case EV_JOINING:
Serial.println(F("EV_JOINING")); break;
case EV_JOINED:
Serial.println(F("EV_JOINED")); break;
case EV_RFU1:
Serial.println(F("EV_RFU1")); break;
case EV_JOIN_FAILED:
Serial.println(F("EV_JOIN_FAILED")); break;
case EV_REJOIN_FAILED:
Serial.println(F("EV_REJOIN_FAILED"));
break;
case EV_TXCOMPLETE:
Serial.println(F("EV_TXCOMPLETE (includes waiting for RX windows)")); if (LMIC.txrxFlags & TXRX_ACK)
Serial.println(F("Received ack"));
if (LMIC.dataLen) {
Serial.println(F("Received ")); Serial.println(LMIC.dataLen); Serial.println(F(" bytes of payload"));
}
// Schedule next transmission
os_setTimedCallback(&sendjob, os_getTime()+sec2osticks(TX_INTERVAL), do_send);
break;
case EV_LOST_TSYNC:
Serial.println(F("EV_LOST_TSYNC")); break;
case EV_RESET:
Serial.println(F("EV_RESET")); break;
case EV_RXCOMPLETE:
// data received in ping slot Serial.println(F("EV_RXCOMPLETE")); break;
case EV_LINK_DEAD:
Serial.println(F("EV_LINK_DEAD")); break;
case EV_LINK_ALIVE:
Serial.println(F("EV_LINK_ALIVE")); break;
default:
Serial.println(F("Unknown event")); break;
}
}
57. orrialdea

/* Funtzioa: void CO2sentsorea (void)
* Zeregina:CO2 sentsorean naurtzea du.
* Erabilitako liburutegiak: DTH11DHT Sensor Library eta Adafruit
* Liburutegia nondik hartuta://https://github.com/adafruit/Adafruit_CCS811 * Bueltatzen duena: ezer
* Sartutako parametroak:
* int
*
* */
void do_send(osjob_t* j){
| // Check if there is not a current TX/RX job running if (LMIC.opmode & OP_TXRXPEND) { Serial.println(F("OP_TXRXPEND, not sending")); } else { // Prepare upstream data transmission at the next possible time. //LMIC_setTxData2(1, mydata, sizeof(mydata)-1, 0); BidalketaLOOP (); Serial.println(F("Packet queued"));

}
| // Next TX is scheduled after TX_COMPLETE event.
}
void tntSETUP (void){
| Serial.println(F("Starting"));
| #ifdef VCC_ENABLE // For Pinoccio Scout boards pinMode(VCC_ENABLE, OUTPUT); digitalWrite(VCC_ENABLE, HIGH); delay(1000); #endif
| // LMIC init os_init(); // Reset the MAC state. Session and pending data transfers will be discarded. LMIC_reset();
| // Set static session parameters. Instead of dynamically establishing a session // by joining the network, precomputed session parameters are be provided. #ifdef PROGMEM // On AVR, these values are stored in flash and only copied to RAM // once. Copy them to a temporary buffer here, LMIC_setSession will // copy them into a buffer of its own again. uint8_t appskey[sizeof(APPSKEY)]; uint8_t nwkskey[sizeof(NWKSKEY)]; memcpy_P(appskey, APPSKEY, sizeof(APPSKEY)); memcpy_P(nwkskey, NWKSKEY, sizeof(NWKSKEY)); LMIC_setSession (0x1, DEVADDR, nwkskey, appskey); #else // If not running an AVR with PROGMEM, just use the arrays directly LMIC_setSession (0x1, DEVADDR, NWKSKEY, APPSKEY); #endif
| #if defined(CFG_eu868) // Set up the channels used by the Things Network, which corresponds // to the defaults of most gateways. Without this, only three base // channels from the LoRaWAN specification are used, which certainly // works, so it is good for debugging, but can overload those // frequencies, so be sure to configure the full frequency range of // your network here (unless your network autoconfigures them). // Setting up channels should happen after LMIC_setSession, as that // configures the minimal channel set. // NA-US channels 0-71 are configured automatically
58. orrialdea

LMIC_setupChannel(0, 868100000, DR_RANGE_MAP(DR_SF12, DR_SF7), BAND_CENTI); // g-band
LMIC_setupChannel(1, 868300000, DR_RANGE_MAP(DR_SF12, DR_SF7B), BAND_CENTI); // g-band
LMIC_setupChannel(2, 868500000, DR_RANGE_MAP(DR_SF12, DR_SF7), BAND_CENTI); // g-band
LMIC_setupChannel(3, 867100000, DR_RANGE_MAP(DR_SF12, DR_SF7), BAND_CENTI); // g-band
LMIC_setupChannel(4, 867300000, DR_RANGE_MAP(DR_SF12, DR_SF7), BAND_CENTI); // g-band
LMIC_setupChannel(5, 867500000, DR_RANGE_MAP(DR_SF12, DR_SF7), BAND_CENTI); // g-band
LMIC_setupChannel(6, 867700000, DR_RANGE_MAP(DR_SF12, DR_SF7), BAND_CENTI); // g-band
LMIC_setupChannel(7, 867900000, DR_RANGE_MAP(DR_SF12, DR_SF7), BAND_CENTI); // g-band
LMIC_setupChannel(8, 868800000, DR_RANGE_MAP(DR_FSK, DR_FSK), BAND_MILLI); // g2-band
// TTN defines an additional channel at 869.525Mhz using SF9 for class B // devices' ping slots. LMIC does not have an easy way to define set this // frequency and support for class B is spotty and untested, so this
// frequency is not configured here.
#elif defined(CFG_us915)

// NA-US channels 0-71 are configured automatically
// but only one group of 8 should (a subband) should be active
// TTN recommends the second sub band, 1 in a zero based count.
// https://github.com/TheThingsNetwork/gateway-conf/blob/master/US-global_conf.jsonLMIC_selectSubBand(1);
#endif

// Disable link check validation
LMIC_setLinkCheckMode(0);

// TTN uses SF9 for its RX2 window.
LMIC.dn2Dr = DR_SF9;

// Set data rate and transmit power for uplink (note: txpow seems to be ignored by the library)
LMIC_setDrTxpow(DR_SF7,14);

// Start job
do_send(&sendjob);
}
void tntLOOP (void){
os_runloop_once();
}
59. orrialdea

# 12 Egindako sistemaren argazkia


60. orrialdea

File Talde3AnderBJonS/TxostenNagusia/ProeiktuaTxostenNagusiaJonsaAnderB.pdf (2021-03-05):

# LoRa proiektua


Egileak

Jon.S eta Ander.B

1. orrialdea
lan hau IURRETA LHIIk sortu du eta Creative Commons lizentzia (https://creativecommons.org/licenses/by-nc/4.0/deed.eu) baten mende dago.

## Ziklo bukaerako proiektua: aurkibidea

2. orrialdea

3. orrialdea

# 1 Erronkaren planteamendua

Erronka honetan bi sentsore erabiliko ditugu, DHT-11 hezetasun eta tenperatura sentsorea eta CJMU-811 edo CCS-811 aireko CO2 kantitatea eta TVOC (bolatil konposatu organikoak) neurtze duena.
ESP32 TTGO kontrolagailuarekin lan egingo dugu, eta LORA komunikazioa erabiliko dugu, gure kontrolagailua, konfiguratu dugun GateWay-arekin komunikatzeko eta balioak partekatu ahal izateko. Ondoren GateWay-a konfiguratu dugu TTN (The things Network)ean sortu dugun kontu batean sentsoreetako balioak bertan bistaratzeko.
Eta azkenik Raspberry bat erabiliz dashboard edo aginte panel bat sortzeko eta hor partekatzeko gure ditugun balioak edo informazioa.
Gure helburua elektronika eraikinaren geletako CO2 kantiatea, tenperatura eta hezetasunaren kontrola izatea da, eta edozein lekutan egonda, balio hauek ikus ahal izatea.


4. orrialdea

# 2 Hausnarketak

# 2.1 HLK-PM03 AC DC

HLK-PM03 AC DC bihurgailua elikadura-iturri, botere-iturri edo iturri kommutatu deitzen den gailu elektroniko bat da. Elektronikan, korronte alternoa irteera batean edo gehiagotan korronte zuzen bihurtzen duen tresna da.

HLK-PM03 AC DC)


# 2.1.1 DHT11

DHT-11 erabiliko ditugun sentsoreetako bat izango da, sentsore hau tenperatura eta hezetasuna neurtzuko balio du, gure kasuan erabiliko duguna 3 pin ditu, eskumako irudian ikusten denez.

Tenperatura ºCtan neurtzen du eta hezetasuna %tan.
Kostu txikiko eta erabiltzeko erraza den sentsorea da.Hezetasun kapazitarioaren sentsorea eta termistore bat integratzen ditu inguruko airea neurtzeko, eta datuak seinale digital baten bidez erakusten ditu signal pinean (ez du irteera analogikorik)
5. orrialdea


DHT11 aukeratu dugu sentsore honekin tenperatura eta hezetazuna jakin dezakegu eta aurretik probak egin dugu eta montatzerako orduan erraza izan da.

# CJMCU-811

CCS811 airearen kalitatearen sentsorea oso potentzia txikiko gas digitalaren sentsore detektatzaile bat da, oxido metalikoko gas-sentsore bat duena konposatu organiko lurrunkorren gama zabal bat identifikatzeko, airearen kalitatea monitorizatzeko ADC bat eta I2C interfaze bat ematen dituen mikrokontrolagailu batekin.

CCS811 argi-sentsorea gas digitalaren sentsorerik onena da airearen kalitatea zehazki monitorizatzeko, Arduino, STM32, Raspberry Pi eta abar erabiliz. Ccs811 gy-811 breakout board sentsorearen modulu hau tamaina txiki, gama zabal eta bereizmen handikoa da.

Sentsore hau gadget pertsonaletako (smartwatchak eta telefonoak) barneko airearen kalitatearen jarraipena egiteko diseinatuta dago. Erraz iristeko, CJMCU-811 modulua nahiago da I2C gailu estandar gisa erabili ahal izateko.

Sentsore hau aukeratu dugu erraza izan delako montatzerakoan. Bere abantaila onetarikoa da ez duela energia asko kontsumitzen eta bebai aukeratu dugu eskuragarri izan dugulako.

ABANTAILAK
Sentsorea eragiteko moduak kudeatzen ditu eta
KOLak detektatzen diren bitartean neurketak egitea
ECO2-aren maila edo KOLen indikazioa ematen du Ostatuaren esku-hartzea
Hardware eta softwarearen integrazioa errazten du Bateriaren iraupena zabaltzen du aplikazio eramangarrietan Faktorea modu txikian diseinatzeko egokia
Aurreztu% 60rainoko tartea zirkuitu inprimatuaren plakan
6. orrialdea

Bolumen eta fidagarritasun handirako diseinatua (>5 urteko balio-bizitza)


# 2.1.4 ESP32 TTGO LORA

ESP-32 RF modulu generiko indartsua da, WiFi eta Bluetooth funtzioekin. WiFi eta Bluetooth konbinazio dualak modulu hau aplikazio askotara bideratzea ahalbidetzen du. Modulu honi erantsita, bi nukleoko PUZ bat gehitu da, 80 MHz eta 24 MHz artean konfigura daitekeen erloju-osziladore batekin batera kontrola daitekeena. ESP-32ak ere kontsumo baxuko modu bat dauka, efizientzia distiratsu baterako modu anitzekin.

# Ezaugarriak eta abantailak:

- 2,4 GHz-ko tarteak distantzia eta irismen handia ematen du.
- PUZ kontrolagarria eta erloju-osziladorea
- Funtzio anitzeko txipa; WiFi eta Bluetooth
- Bateragarria honako hauekin: IPv4, IPv6, SSL, TCP/UDP/http/FTP/MQTT
- 150 Mbps-era arteko datu-tartea du.
- WiFi segurtasuna: WPA, WPA2, WPA2-Enterprise-WPS
- Funtzionamendu-tentsioa: 2,7/3,6V kargaren arabera
- -40 ° C - +85 ° C funtzionamendu-tenperaturak
- Periferiko integratuak: ADC eta DAC funtzioak, ukimen-sentsorea, host SD/SDIO/MMC kontrolatzailea, I2C eta I2S interfazea, SPI interfazea, infragorrien kontrolatzailea eta hardware-azeleragailua

ESP32 TTGO aukeratu dugu eskuragarri izan dugulako eta ere gure proiektuan lora erabili behar dugunez gai da mezuak distantzia oso luzetara bidaltzeko.

7. orrialdea

8. orrialdea

# 3 Bloke-diagramak

# 3.1 Softwarearen hasierako bloke-diagrama


9. orrialdea

# 3.2 Hardwarearen hasierako bloke-diagrama


10. orrialdea

# 4 Osagaien analisia

# 4.1 DHT-11

# 4.1.1 Sarrera


DHT-11 erabiliko ditugun sentsoreetako bat izango da, sentsore hau tenperatura eta hezetasuna neurtzuko balio du, gure kasuan erabiliko duguna 3 pin ditu, eskumako irudian ikusten denez.

Tenperatura ºCtan neurtzen du eta hezetasuna %tan.

Kostu txikiko eta erabiltzeko erraza den sentsorea da.Hezetasun kapazitarioaren sentsorea eta termistore bat integratzen ditu inguruko airea neurtzeko, eta datuak seinale digital baten bidez erakusten ditu signal pinean (ez du irteera analogikorik).

Datasheet Link

https://components101.com/sites/default/files/component_datasheet/DHT11-Temperature-Sensor.pdf (https://components101.com/sites/default/files/component_datasheet/DHT11-Temperature-Sensor.pdf)

Ezaugarriak:

- Kontsumoa = 2,5mA
- Irteera seinalea = Digitala
- Tenperatura maila = 0ºC – 50ºC
- Hezetasun maila = 20 % - 90 %

# 4.1.2 Eskema elektronikoak

11. orrialdea

# 4.1.3 Sentsorearen edo shieldaren pinout-a

Berezitasunik balego adierazi hemen (pull-up erresistentziak, tentsio balioen mugak...)

# 4.1.4 Oinarrizko programa

#include "DHT.h"

// Uncomment whatever type you're using!
#define DHTTYPE DHT11 // DHT 11

//#define DHTTYPE DHT22 // DHT 22 (AM2302), AM2321
//#define DHTTYPE DHT21 // DHT 21 (AM2301)

// Connect pin 1 (on the left) of the sensor to +5V
// NOTE: If using a board with 3.3V logic like an Arduino Due connect pin 1 // to 3.3V instead of 5V!
// Connect pin 2 of the sensor to whatever your DHTPIN is
// Connect pin 4 (on the right) of the sensor to GROUND
// Connect a 10K resistor from pin 2 (data) to pin 1 (power) of the sensor

const int DHTPin = 5; // what digital pin we're connected to

DHT dht(DHTPin, DHTTYPE);

void setup() {
Serial.begin(9600);
Serial.println("DHTxx test!");

dht.begin();
}

void loop() {
// Wait a few seconds between measurements.
delay(2000);

// Reading temperature or humidity takes about 250 milliseconds! float h = dht.readHumidity();
float t = dht.readTemperature();

if (isnan(h) || isnan(t)) {
Serial.println("Failed to read from DHT sensor!"); return;
}

Serial.print("Humidity: ");
Serial.print(h);
Serial.print(" %\t");
Serial.print("Temperature: "); Serial.print(t);
Serial.println(" *C ");

}

12. orrialdea

# 4.1.5 Oinarrizko programa funtzioak bihurtuta

Nagusia:

/*-----( LIBURUTEGIAK )----*/ //CO2
#include "Adafruit_CCS811.h" Adafruit_CCS811 ccs;

//DHT11
#include "DHT.h"

/*-----( KONSTANTEAK )-----*/
#define DHTTYPE DHT11 // DHT 11

const int DHTPin = 5; // what digital pin we're connected to

/*-----( OBJETUAK )-----*/

//DHT-11
DHT dht(DHTPin, DHTTYPE);

/*-----( ALDAGAIAK )----*/
//Programa osoan zehar erabiliko diren aldagai orokorrak

//Komunikazio serierako aldagaiak

/*-----( FUNTZIOAK )----*/
float dhtSentsoreaLoop(void); void CO2SentsoreaLoop();
void C02SentsoreaSetup();
void dhtSentsoreaSetup();

void setup() {
// put your setup code here, to run once: Serial.begin(9600);
dhtSentsoreaSetup();
C02SentsoreaSetup();

}

void loop() {

dhtSentsoreaLoop();

CO2SentsoreaLoop();

}
// put your main code here, to run repeatedly:

CO2:

/* Funtzioa: CO2 sentsorea
* Zeregina: Funtzio honek C02 sentsoreak neurtutako balioak irakurtzeko * Erabilitako liburutegiak: https://github.com/adafruit/Adafruit_CCS811 * Bueltatzen duena: C02 eta TVOC neurketa
* Sartutako parametroak: ezer
* */

void C02SentsoreaSetup()

13. orrialdea

{
Serial.println("CCS811 test");

if(!ccs.begin()){
Serial.println("Failed to start sensor! Please check your wiring."); while(1);
}
while(!ccs.available());

}

void CO2SentsoreaLoop() {
if(ccs.available()){
if(!ccs.readData()){
Serial.print("CO2: ");
Serial.print(ccs.geteCO2()); Serial.print("ppm, TVOC: "); Serial.println(ccs.getTVOC()); }
else{
Serial.println("ERROR!");
while(1);
}
}
delay(500);
}

DHT-11:

/* Funtzioa: DHT-11 sentsorea

* Zeregina: Funtzio honek DHT-11 sentsoreak neurtutako balioak irakurtzeko * Erabilitako liburutegiak: https://github.com/adafruit/DHT-sensor-library * Bueltatzen duena: Tenperatura eta hezetasun neurketa
* Sartutako parametroak: ezer
* */
void dhtSentsoreaSetup()
{
Serial.println("DHTxx test!");

dht.begin();
}

float dhtSentsoreaLoop(void) {

// Wait a few seconds between measurements.
delay(2000);

// Reading temperature or humidity takes about 250 milliseconds! float h = dht.readHumidity();
float t = dht.readTemperature();

if (isnan(h) || isnan(t)) {
Serial.println("Failed to read from DHT sensor!"); return;
}
Serial.print("Humidity: ");
Serial.print(h);
Serial.print(" %\t");
Serial.print("Temperature: "); Serial.print(t);
Serial.println(" *C ");
14. orrialdea

}

# 4.1.6 Material zerrenda

Nahi duzuen formatuan, sistema hau gauzatzeko material zerrenda. Gutxienez, azpiko taulan agertzen diren atalak agertu behar dira:

Izena | Kopurua | Oharrak edota ezaugarri bereziak
DHT-11 | 1 | 3 pin
ESP32 kontrolagailua | 1 | Nodo

# 4.1.7 Gorabeherak

Ez ditugu izan gorabeherarik atal honetan

# 4.2 CJMCU-811

# 4.2.1 Sarrera

https://innovatorsguru.com/ccs811-arduino-code/

https://innovatorsguru.com/wp-content/uploads/2020/01/CCS811_Datasheet-DS000459.pdf

CCS811 airearen kalitatearen sentsorea oso potentzia txikiko gas digitalaren sentsore detektatzaile bat da, oxido metalikoko gas-sentsore bat duena konposatu organiko lurrunkorren gama zabal bat identifikatzeko, airearen kalitatea monitorizatzeko ADC bat eta I2C interfaze bat ematen dituen mikrokontrolagailu batekin.

CCS811 argi-sentsorea gas digitalaren sentsorerik onena da airearen kalitatea zehazki monitorizatzeko, Arduino, STM32, Raspberry Pi eta abar erabiliz. Ccs811 gy-811 breakout board sentsorearen modulu hau tamaina txiki, gama zabal eta bereizmen handikoa da.

Sentsore hau gadget pertsonaletako (smartwatchak eta telefonoak) barneko airearen kalitatearen jarraipena egiteko diseinatuta dago. Erraz iristeko, CJMCU-811 modulua nahiago da I2C gailu estandar gisa erabili ahal izateko.

15. orrialdea


# 4.2.2 Eskema elektronikoak


# 4.2.3 Sentsorearen edo shieldaren pinout-a


Datasheet:https://cdn-learn.adafruit.com/downloads/pdf/adafruit-ccs811-air-quality-sensor.pdf

# 4.2.4 Oinarrizko programa

#include "Adafruit_CCS811.h"

Adafruit_CCS811 ccs;

void setup() {
Serial.begin(9600);
16. orrialdea

Serial.println("CCS811 test");

if(!ccs.begin()){
Serial.println("Failed to start sensor! Please check your wiring."); while(1);
}

// Wait for the sensor to be ready
while(!ccs.available());
}

void loop() {
if(ccs.available()){
if(!ccs.readData()){
Serial.print("CO2: ");
Serial.print(ccs.geteCO2()); Serial.print("ppm, TVOC: "); Serial.println(ccs.getTVOC()); }
else{
Serial.println("ERROR!");
while(1);
}
}
delay(500);
}

# 4.2.5 Oinarrizko programa funtzioak bihurtuta

Nagusia:

/*-----( LIBURUTEGIAK )----*/ //CO2
#include "Adafruit_CCS811.h" Adafruit_CCS811 ccs;

//DHT11
#include "DHT.h"

/*-----( KONSTANTEAK )-----*/
#define DHTTYPE DHT11 // DHT 11

const int DHTPin = 5; // what digital pin we're connected to

/*-----( OBJETUAK )-----*/

//DHT-11
DHT dht(DHTPin, DHTTYPE);

/*-----( ALDAGAIAK )----*/
//Programa osoan zehar erabiliko diren aldagai orokorrak

//Komunikazio serierako aldagaiak

/*-----( FUNTZIOAK )----*/
float dhtSentsoreaLoop(void); void CO2SentsoreaLoop();
void C02SentsoreaSetup();
void dhtSentsoreaSetup();
17. orrialdea

void setup() {
// put your setup code here, to run once: Serial.begin(9600);
dhtSentsoreaSetup();
C02SentsoreaSetup();

}

void loop() {

dhtSentsoreaLoop();

CO2SentsoreaLoop();

}
// put your main code here, to run repeatedly:

CO2:

/* Funtzioa: CO2 sentsorea
* Zeregina: Funtzio honek C02 sentsoreak neurtutako balioak irakurtzeko * Erabilitako liburutegiak: https://github.com/adafruit/Adafruit_CCS811 * Bueltatzen duena: C02 eta TVOC neurketa
* Sartutako parametroak: ezer
* */

void C02SentsoreaSetup()
{
Serial.println("CCS811 test");

if(!ccs.begin()){
Serial.println("Failed to start sensor! Please check your wiring."); while(1);
}
while(!ccs.available());

}

void CO2SentsoreaLoop() {
if(ccs.available()){
if(!ccs.readData()){
Serial.print("CO2: ");
Serial.print(ccs.geteCO2()); Serial.print("ppm, TVOC: "); Serial.println(ccs.getTVOC()); }
else{
Serial.println("ERROR!");
while(1);
}
}
delay(500);
}

DHT-11:

/* Funtzioa: DHT-11 sentsorea

* Zeregina: Funtzio honek DHT-11 sentsoreak neurtutako balioak irakurtzeko * Erabilitako liburutegiak: https://github.com/adafruit/DHT-sensor-library * Bueltatzen duena: Tenperatura eta hezetasun neurketa

18. orrialdea

* Sartutako parametroak: ezer * */
void dhtSentsoreaSetup()
{
Serial.println("DHTxx test!");

dht.begin();
}

float dhtSentsoreaLoop(void) {

// Wait a few seconds between measurements.
delay(2000);

// Reading temperature or humidity takes about 250 milliseconds! float h = dht.readHumidity();
float t = dht.readTemperature();

if (isnan(h) || isnan(t)) {
Serial.println("Failed to read from DHT sensor!"); return;
}
Serial.print("Humidity: ");
Serial.print(h);
Serial.print(" %\t");
Serial.print("Temperature: "); Serial.print(t);
Serial.println(" *C ");

}

# 4.2.6 Material zerrenda

Nahi duzuen formatuan, sistema hau gauzatzeko material zerrenda. Gutxienez, azpiko taulan agertzen diren atalak agertu behar dira:

Izena | Kopurua | Oharrak edota ezaugarri bereziak
4.3 CJMCU-811 edo CCS-811 | 1 | 3,3V-ra konektatu behar da
Arduino nano | 1

# 4.3.1 Gorabeherak

Hasieran errore bat ematen zigun kableatua txarto zegoelako. Errore hori konpontzeko SDA eta SCL haien artean aldatu dugu kablea eta funtzionatu digu.

# 4.4 TTGO Lora ESP32

# 4.4.1 Sarrera

19. orrialdea

ESP32 OLEDek ESP32 modulua eta plaka berean OLED pantaila konbinatzen ditu, wifi eta bluetooth 4.0 konektibitatea eskainiz. Gainera, mikroUSB konektorea dauka elikatzeko eta JST konektorea plaka bera elikatzeko. Arduinoko IDEtik zuzenean programatu daiteke. Plakak LoRa modulu bat ere badu, datuak distantzia handietara bi noranzkotan transmititzea ahalbidetzen duena, The Things Network sarera konektatzeko aukerarekin

# 4.4.2 Pinout

# 4.4.3 ESP32 plaka arduinon zelan instalatu

20. orrialdea

1. Arduinoko zure IDEan,joan Archivo > Preferencias
2. Sartu https://dl.espressif.com/dl/package_esp32_index.json "taula-administratzailearen URL gehigarriak" eremuan, hurrengo irudian agertzen den bezala. Gero, egin klik "onartu" botoian:


3. Ondoren “Herramientas” atalean, plaka jartzen duen eremuan, “Gestor de tarjetas”-ensartu.
21. orrialdea


4. Eta hor zaudenean ESP32 bilatu eta instalatu barik badago instalatu.10 minututan prest egongo da
5. Instalatu eta ondoren, plaka berri hori instalatuta egongo lirake.

Bertan utziko dizuet nik jarraitutako pusuak plaka hau instalatzeko :

https://randomnerdtutorials.com/installing-the-esp32-board-in-arduino-ide-windows-instructions/

22. orrialdea

# 4.4.4 OLED liburutegiak instalatzea

Liburutegi batzuk daude eskuragarri OLED pantaila ESP32 sistemarekin kontrolatzeko. Tutorial honetan Adafruit-eko bi liburutegi erabiliko ditugu: Adafruit_SSD1306 liburutegia eta Adafruit_GFX liburutegia.

Jarraitu hurrengo urratsak liburutegi horiek instalatzeko.

1. Ireki ezazu Arduinoren IDE eta joan Sketch > Incluir biblioteca > Administrar bibliotecas. Liburutegiko administratzailea ireki beharko litzateke.
2. Idatzi | "SSD1306" | bilaketa-koadroan | eta | instalatu Adafruit-eko | SSD1306 | liburutegia.


3. Adafruit-eko SSD1306 liburutegia instalatu ondoren, idatzi "GFX" bilaketa-koadroan eta instalatu liburutegia.
23. orrialdea


# 4.5 Led NeoPixel

# 4.5.1 Sarrera

NeoPixelak 5050 motako Led diodoak dira, WS2812 kontrolagailu integratu batekin. Hainbat neurri eta formatan daude, eta dokumentazio zabala dute, tutoretzak eta Arduinorekin erabiltzeko prest dauden liburu-dendak. Oso erraza da minutu gutxitan martxan jartzea, pin bat besterik ez baitute behar eta kolore distiratsuak eskaintzen baitituzte!

Ezaugarriak:

Forma: Laukizuzena
Pixel kopurua: 8
Neurriak: 51x10x3mm
Pisua: 2.57 gramo
Elikadura: 5V-3,3V
Kontsumoa: 18 mA pixel bakoitzeko

Datasheet:

https://cdn-shop.adafruit.com/datasheets/WS2812.pdf

# 4.5.2 Eskema elektrikoa

24. orrialdea

# 4.5.3 Sentsorearen edo shieldaren pinout-a

# 4.5.4 Oinarrizko programa

// NeoPixel Ring simple sketch (c) 2013 Shae Erisson
// Released under the GPLv3 license to match the rest of the // Adafruit NeoPixel library

#include <Adafruit_NeoPixel.h>

#ifdef __AVR__

#include <avr/power.h> // Required for 16 MHz Adafruit Trinket #endif

// Which pin on the Arduino is connected to the NeoPixels?
#define PIN | 6 // On Trinket or Gemma, suggest changing this to 1

25. orrialdea

// How many NeoPixels are attached to the Arduino?
#define NUMPIXELS 16 // Popular NeoPixel ring size

// When setting up the NeoPixel library, we tell it how many pixels, // and which pin to use to send signals. Note that for older NeoPixel // strips you might need to change the third parameter -- see the
// strandtest example for more information on possible values. Adafruit_NeoPixel pixels(NUMPIXELS, PIN, NEO_GRB + NEO_KHZ800);

#define DELAYVAL 500 // Time (in milliseconds) to pause between pixels

void setup() {
// These lines are specifically to support the Adafruit Trinket 5V 16 MHz. // Any other board, you can remove this part (but no harm leaving it): #if defined(__AVR_ATtiny85__) && (F_CPU == 16000000) clock_prescale_set(clock_div_1);
#endif

// END of Trinket-specific code.

pixels.begin(); // INITIALIZE NeoPixel strip object (REQUIRED) }

void loop() {
pixels.clear(); // Set all pixel colors to 'off'

// The first NeoPixel in a strand is #0, second is 1, all the way up // to the count of pixels minus one.
for(int i=0; i<NUMPIXELS; i++) { // For each pixel...

// pixels.Color() takes RGB values, from 0,0,0 up to 255,255,255 // Here we're using a moderately bright green color: pixels.setPixelColor(i, pixels.Color(0, 150, 0));

pixels.show(); // Send the updated pixel colors to the hardware.

delay(DELAYVAL); // Pause before next pass through loop
}
}

# 4.5.5 Material zerrenda

Izena | Kopurua | Oharrak edota ezaugarri bereziak
Led Neopixel | 1
TTGO Lora | 1

# 4.5.6 Gorabeherak

Ez dugu izan.

# 4.5.7 Estekak

https://learn.adafruit.com/adafruit-neopixel-uberguide/

https://tienda.bricogeek.com/led-neopixel/660-barra-neopixel-8-x-ws2812.html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 (https://tienda.bricogeek.com/led-neopixel/660-barra-neopixel-8-x-ws2812.html)

26. orrialdea

# 4.6 Elikatze Iturria (HLK-PM03 AC DC)

# 4.6.1 Sarrera

HLK-PM03 AC DC bihurgailua elikadura-iturri, botere-iturri edo iturri kommutatu deitzen den gailu elektroniko bat da. Elektronikan, korronte alternoa irteera batean edo gehiagotan korronte zuzen bihurtzen duen tresna da.

HLK-PM03 AC DC bihurgailua espazio trinkoetan inplementatu daiteke, edo proiektuak ahalik eta txikiena izan behar badu, iturri hori adierazitakoa da.


Energia elektrikoa VCA izatetik VCD izatera aldatzean, hainbat gailu elektroniko elikatu ditzake, hala nola CD motorra, led-ak, txartelak edo Arduino moduluak, wifi modulua, sentsoreak, eragingailuak, anplifikadoreak, zirkuitu integratuak, etab.

Ezaugarriak:

Tipo: HLK-PM03 Convertidor AC DC.

- Voltaje de entrada: AC100-240V 50/60Hz.
- Voltaje de salida: 3.3 VCD a 909mA.
- Potencia Máxima de salida: 3W.
- Eficiencia en voltaje de salida: 70%
27. orrialdea

# 4.6.2 PinOut


- Bajo rizado y bajo nivel de ruido.
- Salida de protección contra sobrecarga y cortocircuito.
- Pines: 4.

# 4.6.3 Eskema elektrikoa

28. orrialdea

# 5 ESP32 TTGO pinen esleipena

PLAKAKO ELIKADURA | KANPOKO ELIKADURA | ERABILERA
VI N | 5V | 3V3 | GND | RESE T | V | mA
| | | | | 3,3 | 20 | TTGO Lora
| | X | | | | 2,5 | DHT11 (Tenperatura eta Hezetasuna)
| | X | | | | 10 | CJMCU-811(CO2_Sentsorea)
| | X | | | | 480 | LED NEOPIXEL
| | | | | 220 V | 900 | HLK-PM03 AC-DC 220 V a 3,3V


29. orrialdea

DIGITALA | KOMUNIKAZIOAK | GAINERAKOAK | ERABILERA
GPI0/GPO0
GPI1/GPO1 | UART TxD | | Ordenagailuarekin komunikatzeko (Serial) Datuak jaso
GPI2/GPO2
GPI3/GPO3 | UART RxD | | Ordenagailuarekin komunikatzeko (Serial) Datuak bidali
| | | OLED_SDA--CJMCU-811(CO2_Sentsorea)
GPI4/GPO4 | | SDA
| | SPI CSO | LORA_SCK
| GPI5/GPO5
GPI12/GPO12
| GPI13/GPO13 | | LED NEOPIXEL
| | | | LORA_RST
GPI15/GPO15 | | | SCL
| | | U2 RXD | | OLED_RST
| GPI17/GPO17
| | | SPI CLK | | LORA_CS
| GPI19/GPO19
| | | | CJMCU-811(CO2_Sentsorea)
| GPI22/GPO22 | SCL(jumper)

GPI14/GPO14
| | | | | OLED_SCL--CJMCU-811(CO2_Sentsorea)
| GPI16/GPO16
| | | U2 TXD | | DHT11 (Tenperatura eta Hezetasuna)
| GPI18/GPO18
| | | | | LORA_MISO
GPI21/GPO21 | | SDA(jumper)
| | | | CJMCU-811(CO2_Sentsorea)
GPI23/GPO23
GPI24/GPO24
GPI25/GPO25
| | LORA_IRQ

GPI26/GPO26
| | LORA_MOSI
| GPI27/GPO27
GPI32/GPO32
GPI3/GPO33
GPI34/GPO34
GPI35/GPO35

# 6 Eskema elektrikoak


Kicad eskema

PCB eskema
(Zubiak eginez akatsak zuzendu ditugu)
32. orrialdea

33. orrialdea

# 7 GateWay konfigurazioa

GateWay bat LoRa transmisio modulua duen gailua da eta informazioa Internet eta berarekin komunikatzen diren nodoen artean birbidaltzen du eta alderantziz.

GateWay-a konfiguratzeko tutorial edo manual
bat aurkitu dugu interneten.
Hainbat pasu segi ditugu, honako hauek:
- Lehenengo pausua, gure GateWay-a elikatu ondoren Reset botoia 5 segunduz pultsatzea da, goiko aldean duen LEDa azkar
parpadeatzen(berde-gorri) jarri arte
- Ondoren Setup botoia 10 segunduz
pultsauta mantendu LEDa gorriz
parpadeatzen jarri harte.
- Hau lortu eta gero GateWay-a orain WiFi AP bat erakusten du, SSID MINIHUB-xxxxxx dena, non xxxxxx GateWay-aren IDA da, 6 digito.
- GateWay-aren pasahitza gailuaren atzeko aldean ikus dezakegu.
- Azkenik, 192.168.4.1 sarrera sartu eta hor Wifia aukeratu dugu


34. orrialdea

- Konfigurazioa zuzena bada, Gateway-a berdez kliskatuko du segundo batzuetan, sare horretara konektatzen den bitartean.
- Konfigurazioa zuzena bada, pasabideak BERDE < ->GORRIAN kliskatuko du segundo batzuetan, CUPS azken puntura konektatzen den bitartean, eta LNS trafikoko azken puntura konektatzeko beharrezkoa den informazioa lortzen du.
- Konfigurazioa zuzena izan bada, Led berde finkoan egongo da, eta horrek esan nahi du GateWay-a konektatuta dagoela.
35. orrialdea

# 8 Azken programa osoaren atal desberdinak azalpenekin

PROGRAMA NAGUSIA:

#include "Nagusia.h"

void setup() {
// put your setup code here, to run once: Serial.begin(115200);
dhtSentsoreaSetup();
OledSetup();
C02SentsoreaSetup();
TTNsetup();
NeoPixelsetup();
}

void loop() {

dhtSentsoreaLoop();

OledLoop();

CO2SentsoreaLoop();

TTNloop();

NeoPixelLoop();

}
// put your main code here, to run repeatedly:

BIDALI TTN:

void BidalketaLoop (void){

float h = dht.readHumidity();
float t = dht.readTemperature();

unsigned long balioa =((t*10000000)+(h*10000)+(ccs.geteCO2()));
//bidaliko dugun zenbakizko txurroaren simulazioa, balioa adibide bat da TTTHHCCCC
String payload = String(balioa); | //txurroa string
batera pasatu
static uint8_t payloadChar[10]; | //karaktereen arraya
sortu
payload.toCharArray((char *)payloadChar, sizeof(payloadChar)); //stringa char array bihurtu

// Prepare upstream data transmission at the next possible time. Bidalketa egiteko lekua, payloadChar aldagaia bidaltzen du
LMIC_setTxData2(1, payloadChar, sizeof(payloadChar)-1, 0); Serial.println(F("Packet queued"));
}
36. orrialdea

CO2:

/* Funtzioa: CO2 sentsorea
* Zeregina: Funtzio honek C02 sentsoreak neurtutako balioak irakurtzeko * Erabilitako liburutegiak: https://github.com/adafruit/Adafruit_CCS811 * Bueltatzen duena: C02 eta TVOC neurketa
* Sartutako parametroak: ezer
* */

void C02SentsoreaSetup()
{
Serial.println("CCS811 test");

if(!ccs.begin()){
Serial.println("Failed to start sensor! Please check your wiring."); while(1);
}
while(!ccs.available());

}

void CO2SentsoreaLoop() {
if(ccs.available()){
if(!ccs.readData()){
Serial.print("CO2: ");
Serial.print(ccs.geteCO2()); Serial.print("ppm, TVOC: "); Serial.println(ccs.getTVOC()); }
else{
Serial.println("ERROR!");
while(1);
}
}
delay(500);
}

DHT11:

/* Funtzioa: DHT-11 sentsorea
* Zeregina: Funtzio honek DHT-11 sentsoreak neurtutako balioak irakurtzeko * Erabilitako liburutegiak: https://github.com/adafruit/DHT-sensor-library * Bueltatzen duena: Tenperatura eta hezetasun neurketa
* Sartutako parametroak: ezer
* */
void dhtSentsoreaSetup()
{
Serial.println("DHTxx test!");

dht.begin();
}

void dhtSentsoreaLoop(void) {

// Wait a few seconds between measurements.
delay(2000);

// Reading temperature or humidity takes about 250 milliseconds! float h = dht.readHumidity();
float t = dht.readTemperature();

if (isnan(h) || isnan(t)) {
Serial.println("Failed to read from DHT sensor!");
37. orrialdea

return;
}
Serial.print("Humidity: "); Serial.print(h);
Serial.print(" %\t");
Serial.print("Temperature: "); Serial.print(t);
Serial.println(" *C ");

}

LIBURUTEGIAK, KONSTANTEAK, OBJETUAK, FUNTZIOAK, ALDAGAIAK

Nagusia.h

/*-----( LIBURUTEGIAK )----*/
//CO2Sentsorea
#include "Adafruit_CCS811.h" Adafruit_CCS811 ccs;

//DHT11
#include "DHT.h"

//TTN
#include <lmic.h>

#include <hal/hal.h>

#include <SPI.h>

//Libraries for LoRa
#include <SPI.h>

#include <LoRa.h>

//Libraries for OLED Display #include <Wire.h>
#include <Adafruit_GFX.h>

#include <Adafruit_SSD1306.h>

//NeoPixel
#include <Adafruit_NeoPixel.h>

#ifdef __AVR__

#include <avr/power.h> // Required for 16 MHz Adafruit Trinket

#endif

#define NUMPIXELS 8 // Popular NeoPixel ring size

#define PIN | 13 // On Trinket or Gemma, suggest changing this to 1

Adafruit_NeoPixel pixels(NUMPIXELS, PIN, NEO_GRB + NEO_KHZ800);

/*-----( KONSTANTEAK )-----*/

//DHT-11
#define DHTTYPE DHT11 | // DHT 11

const int DHTPin = 17; | // what digital pin we're connected to

//TTN
static const PROGMEM u1_t NWKSKEY[16] = { 0xCF,0x18,0xAA,0xE4,0xCA,0x60,0xFA,0x73,0x36,0x54,0x3B,0xD3,0x32,0x23,0x91,0x5A } ;//Network session key
static const u1_t PROGMEM APPSKEY[16] = { 0xD4,0x58,0x30,0x4E,0x51,0xD5,0x29,0x58,0x8B,0xD5,0x82,0x76,0xB2,0x80,0x0B,0xD7 };//APP session key
static const u4_t DEVADDR = 0x26013458 ; // <-- Change this address for every node! DEVICE ADDRESS
// These callbacks are only used in over-the-air activation, so they are
38. orrialdea

// left empty here (we cannot leave them out completely unless
// DISABLE_JOIN is set in config.h, otherwise the linker will complain). void os_getArtEui (u1_t* buf) { }
void os_getDevEui (u1_t* buf) { }
void os_getDevKey (u1_t* buf) { }

// Schedule TX every this many seconds (might become longer due to duty // cycle limitations).
const unsigned TX_INTERVAL = 60;

// Pin mapping
const lmic_pinmap lmic_pins = { .nss = 18,
.rxtx = LMIC_UNUSED_PIN,
.rst = 14,
.dio = {26, 33, 32},
};

//OLED

//define the pins used by the LoRa transceiver module #define SCK 5
#define MISO 19

#define MOSI 27

#define SS 18

#define RST 14

#define DIO0 26

//433E6 for Asia
//866E6 for Europe
//915E6 for North America
#define BAND 866E6

//OLED pins
#define OLED_SDA 4

#define OLED_SCL 15

#define OLED_RST 16

#define SCREEN_WIDTH 128 // OLED display width, in pixels

#define SCREEN_HEIGHT 64 // OLED display height, in pixels

int counter = 0;

Adafruit_SSD1306 display(SCREEN_WIDTH, SCREEN_HEIGHT, &Wire, OLED_RST);

/*-----( OBJETUAK )-----*/

//DHT-11
DHT dht(DHTPin, DHTTYPE);

/*-----( ALDAGAIAK )----*/
//Programa osoan zehar erabiliko diren aldagai orokorrak

static uint8_t mydata[] = "Hello, world!";
static osjob_t sendjob;

//Komunikazio serierako aldagaiak

/*-----( FUNTZIOAK )----*/
void dhtSentsoreaLoop(void); void CO2SentsoreaLoop();
void C02SentsoreaSetup();
void dhtSentsoreaSetup();
void TTNsetup();
39. orrialdea

void TTNloop();
void OledSetup();
void OledLoop();
void NeoPixelsetup();
void NeoPixelLoop();
void BidalketaLoop ();

NEOPIXEL:

// NeoPixel Ring simple sketch (c) 2013 Shae Erisson
// Released under the GPLv3 license to match the rest of the // Adafruit NeoPixel library

// When setting up the NeoPixel library, we tell it how many pixels, // and which pin to use to send signals. Note that for older NeoPixel // strips you might need to change the third parameter -- see the
// strandtest example for more information on possible value

void NeoPixelsetup() {
// These lines are specifically to support the Adafruit Trinket 5V 16 MHz. // Any other board, you can remove this part (but no harm leaving it): #if defined(__AVR_ATtiny85__) && (F_CPU == 16000000) clock_prescale_set(clock_div_1);
#endif

// END of Trinket-specific code.

pixels.begin(); // INITIALIZE NeoPixel strip object (REQUIRED) }

void NeoPixelLoop() {
pixels.clear(); // Set all pixel colors to 'off'

// The first NeoPixel in a strand is #0, second is 1, all the way up // to the count of pixels minus one.
//for(int i=0; i<NUMPIXELS; i++) { // For each pixel...

// pixels.Color() takes RGB values, from 0,0,0 up to 255,255,255 // Here we're using a moderately bright green color: if(ccs.geteCO2()>= 400 & ccs.geteCO2()< 500)
{
pixels.setPixelColor(0, pixels.Color(0, 50, 0)); pixels.setPixelColor(1, pixels.Color(0, 50, 0)); pixels.setPixelColor(2, pixels.Color(0, 50, 0)); }
else
{
if(ccs.geteCO2()>= 500 & ccs.geteCO2()< 700) {
pixels.setPixelColor(0, pixels.Color(0, 50, 0)); pixels.setPixelColor(1, pixels.Color(0, 50, 0)); pixels.setPixelColor(2, pixels.Color(0, 50, 0)); pixels.setPixelColor(3, pixels.Color(50, 50, 0)); pixels.setPixelColor(4, pixels.Color(50, 50, 0));

}
else{
if(ccs.geteCO2()>= 700 & ccs.geteCO2()< 1000) {
pixels.setPixelColor(0, pixels.Color(0, 50, 0));
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

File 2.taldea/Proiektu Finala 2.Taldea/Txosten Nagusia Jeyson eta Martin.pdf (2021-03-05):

# Projektu finala


Egileak: Jeyson Rueda eta Martin Malaxetxebarria

Ikasturtea: 2020-2021

1. orrialdea
lan hau IURRETA LHIIk sortu du eta Creative Commons lizentzia (https://creativecommons.org/licenses/by-nc/4.0/deed.eu) baten mende dago.

## Ziklo bukaerako proiektua: aurkibidea

2. orrialdea

3. orrialdea

# 1.Erronkaren Planteamendua

CO2, hezetasuna eta tenperatura neurketa egin eta balio horiek led edota panataila bidez erakutsi, honekin batera balioa horiek The Things Network web orrialdean erakutsi Lore Gateway batekin. Raspberry batekin datu horiek ere eskolako zerbitzarian batean erakutsi.


4. orrialdea
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

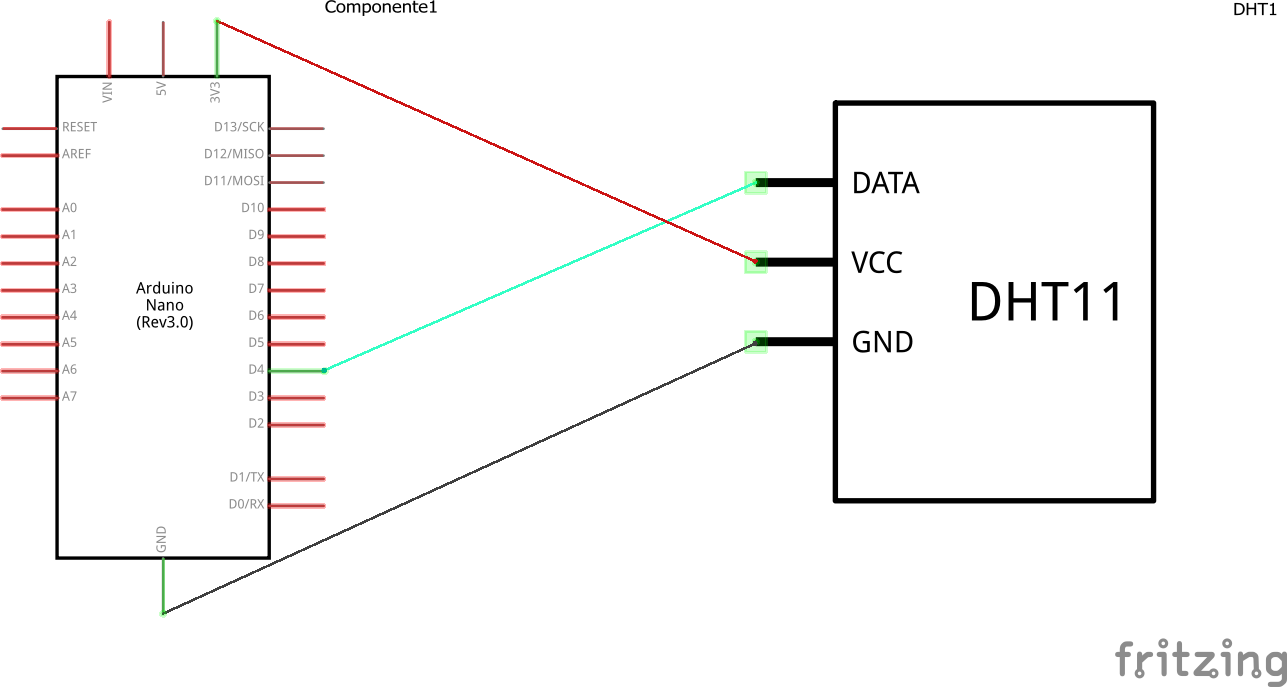
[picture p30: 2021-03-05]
Talde3AnderBJonS/FRITZING/DHT11/DHT11_esquemático.png

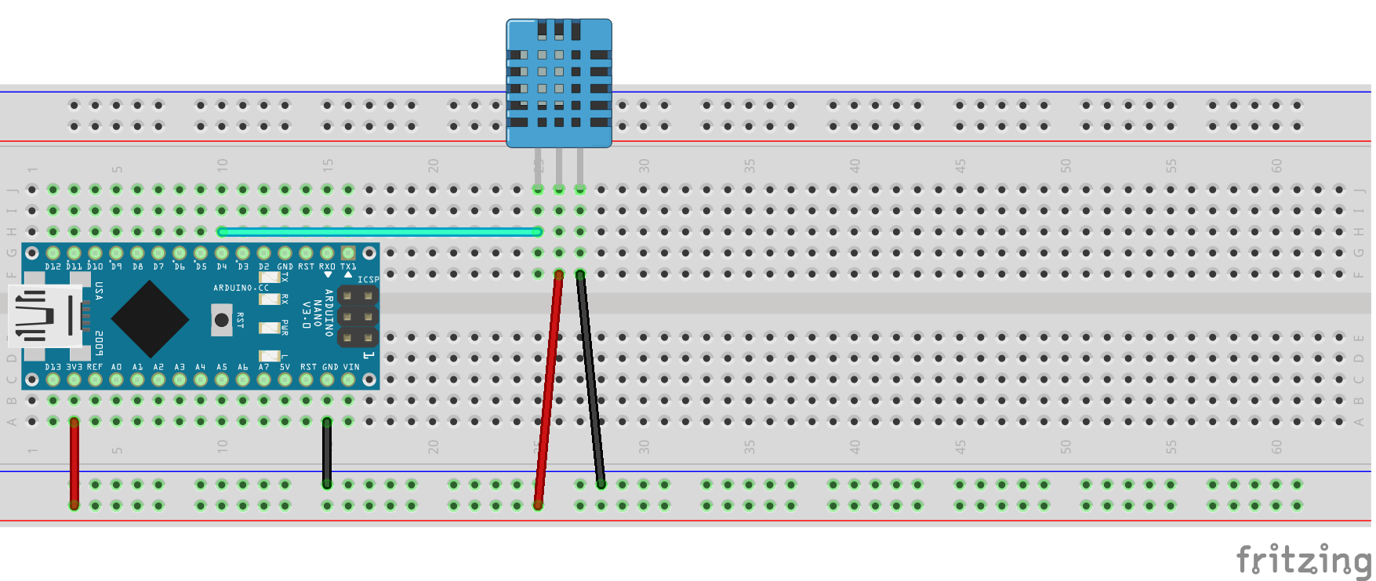
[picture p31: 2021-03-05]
Talde3AnderBJonS/FRITZING/DHT11/DHT11PROTOBOARD.png

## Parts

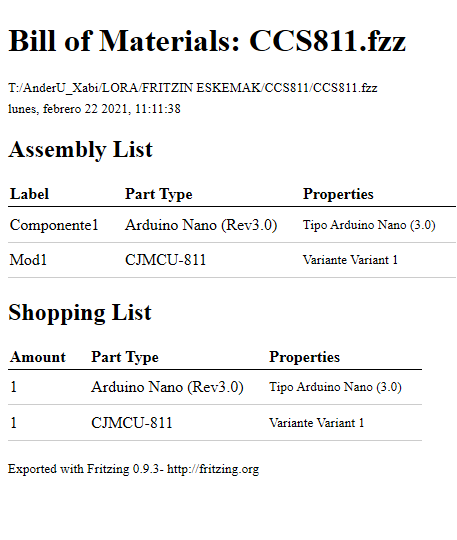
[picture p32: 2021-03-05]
Talde3AnderBJonS/FRITZING/CCS811/LISTA DE MATERIALES.PNG

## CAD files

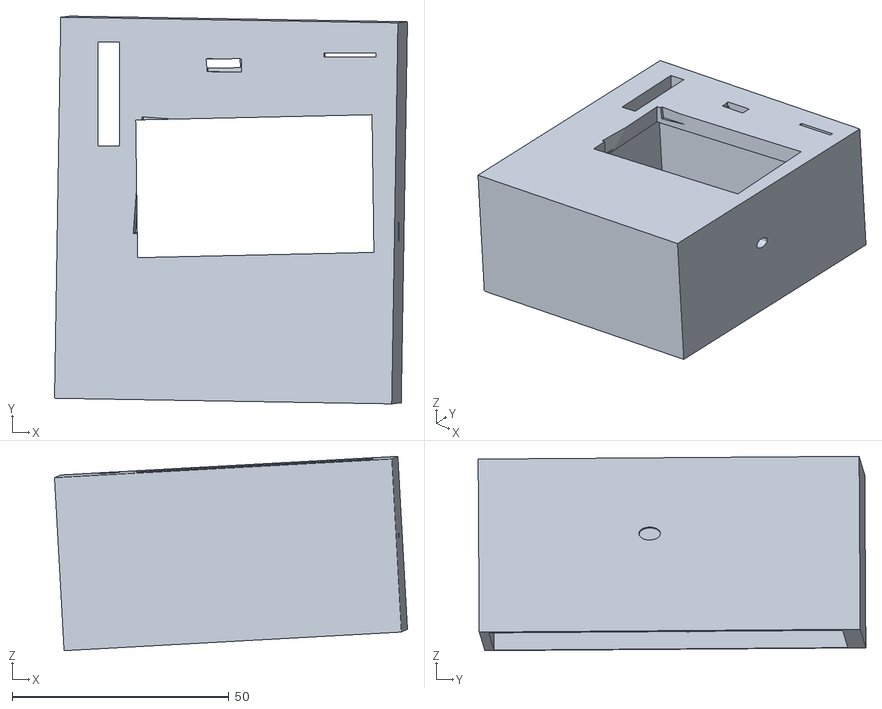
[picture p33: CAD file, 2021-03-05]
2.taldea/Proiektu Finala 2.Taldea/3D/Caja lora(1).stl
81.5 x 89.6 x 44.9

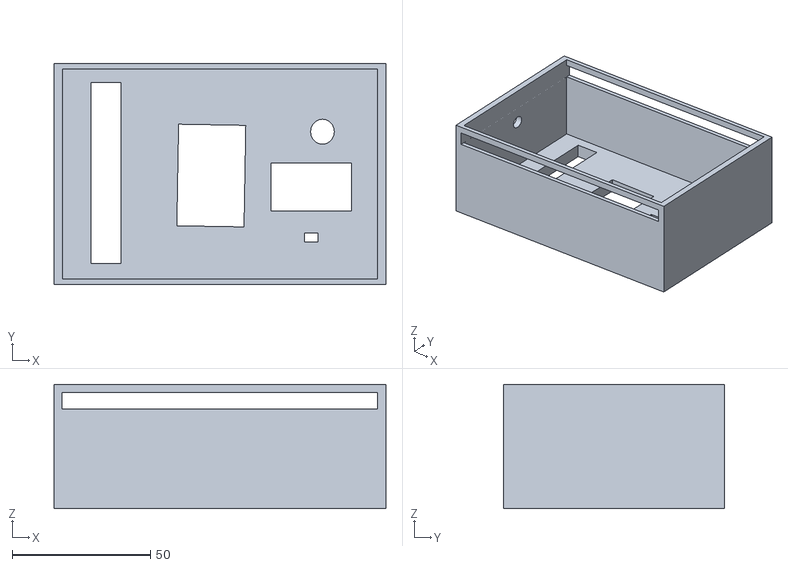
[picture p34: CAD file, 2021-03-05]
4.taldea/3D Kutxa/Copy of Caja con tapa (1).stl
120.0 x 80.0 x 45.0

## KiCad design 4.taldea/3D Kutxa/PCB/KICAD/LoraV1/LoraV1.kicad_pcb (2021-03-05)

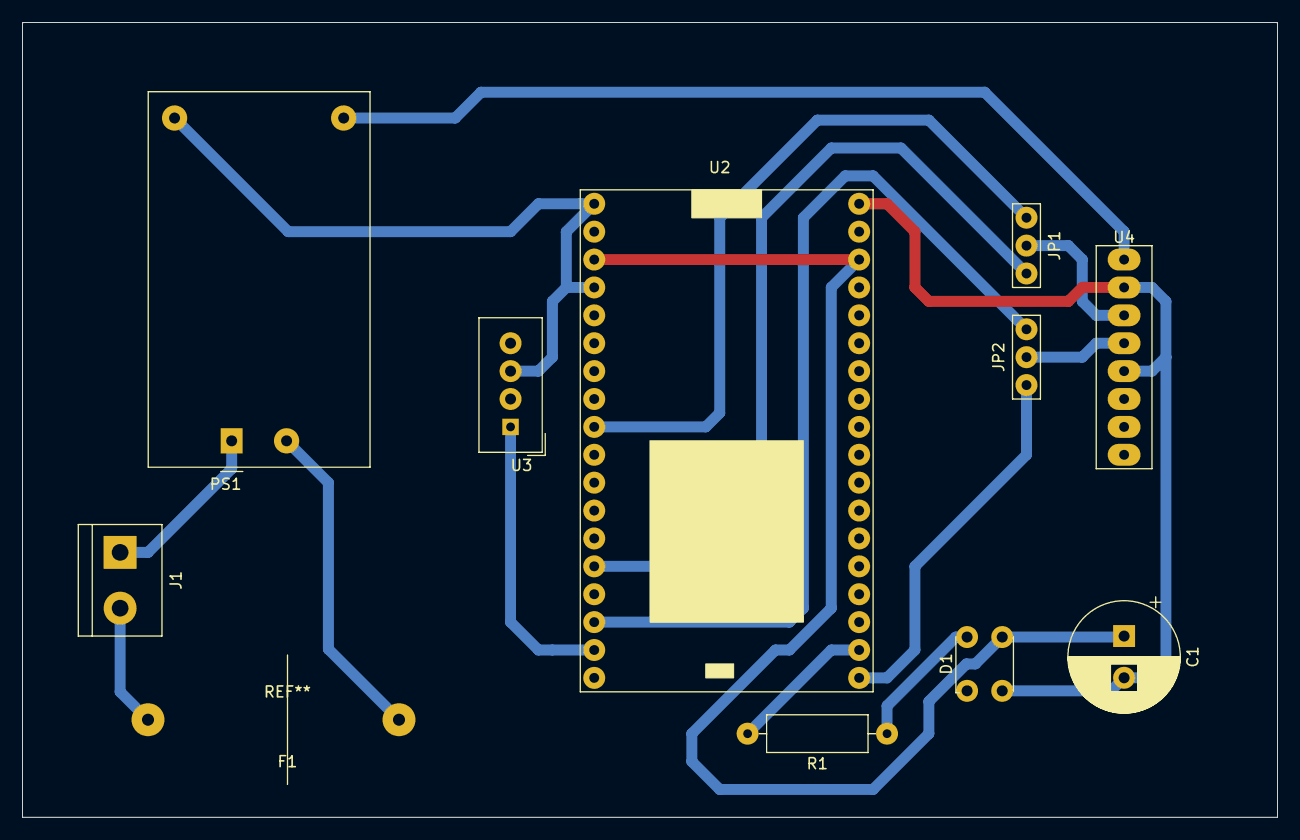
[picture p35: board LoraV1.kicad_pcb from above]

Board: 2 copper layers, 114.3 x 72.4 mm, 11 parts (0 on the bottom side), 16 nets.

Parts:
C1: CP; CP_Radial_D10.0mm_P3.80mm
D1: NeoPixel_THT; LED_Inolux_IN-PI554FCH_PLCC4_5.0x5.0mm_P3.2mm
F1: Fuse; fusiblea
J1: Conn_01x02; TerminalBlock_bornier-2_P5.08mm
JP1, JP2: Jumper_NC_Dual; jumperxabi
PS1: HLK-PM03; Converter_ACDC_HiLink_HLK-PMxx
R1: 470; R_Axial_DIN0309_L9.0mm_D3.2mm_P12.70mm_Horizontal
U2: TTGO; ESP32
U3: DHT11; Aosong_DHT11_5.5x12.0_P2.54mm
U4: RJCMU-811

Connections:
unnamed: C1.1, D1.3, U2.51
unnamed: C1.2, D1.2, U2.52, U4.2, U4.5
unnamed: D1.4, R1.1
unnamed: F1.1, PS1.2
unnamed: F1.2, J1.2
unnamed: J1.1, PS1.1
unnamed: JP1.1, U2.22
unnamed: JP1.2, U4.3
unnamed: JP1.3, U2.15
unnamed: JP2.1, U2.21
unnamed: JP2.2, U4.4
unnamed: JP2.3, U2.4
unnamed: PS1.3, U2.50, U3.3
unnamed: PS1.4, U4.1
unnamed: R1.2, U2.13
unnamed: U2.17, U3.1

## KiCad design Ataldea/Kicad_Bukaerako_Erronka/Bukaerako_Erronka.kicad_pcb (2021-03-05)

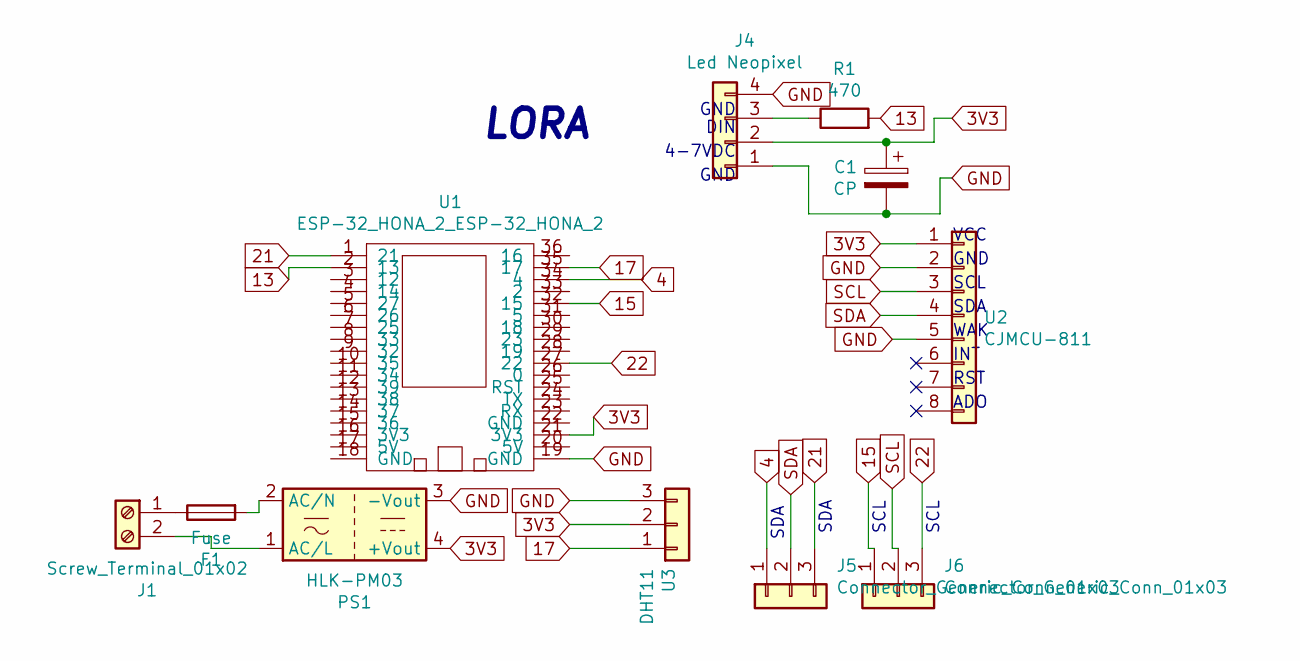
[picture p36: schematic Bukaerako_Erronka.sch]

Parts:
C1: CP; CP_Radial_D10.0mm_P3.80mm
F1: Fuse; Fuseholder_Cylinder-5x20mm_Stelvio-Kontek_PTF78_Horizontal_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
J1: Screw_Terminal_01x02; TerminalBlock_bornier-2_P5.08mm
J4: Led Neopixel; PinSocket_1x04_P2.54mm_Vertical
J5, J6: Connector_Generic_Conn_01x03; PinSocket_1x03_P2.54mm_Vertical
PS1: HLK-PM03; Converter_ACDC_HiLink_HLK-PMxx
R1: 470; R_Axial_DIN0207_L6.3mm_D2.5mm_P7.62mm_Horizontal
U1: ESP-32_HONA_2_ESP-32_HONA_2; ESP_32_HONA_V3
U2: CJMCU-811; PinSocket_1x08_P2.54mm_Vertical
U3: DHT11; PinSocket_1x03_P2.54mm_Vertical

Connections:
3V3: C1.1, J4.2, PS1.4 (+Vout), U1.21 (3V3), U2.1, U3.2
4: J5.1, U1.34 (4)
13: R1.2, U1.2 (13)
15: J6.1, U1.32 (15)
17: U1.35 (17), U3.1
21: J5.3, U1.1 (21)
22: J6.3, U1.27 (22)
GND: C1.2, J4.1, J4.4, PS1.3 (-Vout), U1.19 (GND), U2.2, U2.5, U3.3
unnamed: F1.1, J1.1
unnamed: F1.2, PS1.2 (AC/N)
unnamed: J1.2, PS1.1 (AC/L)
unnamed: J4.3, R1.1
SCL: J6.2, U2.3
SDA: J5.2, U2.4

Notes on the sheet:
VCC
GND
SCL
SDA
WAK
INT
RST
ADO
LORA
DIN
4-7VDC

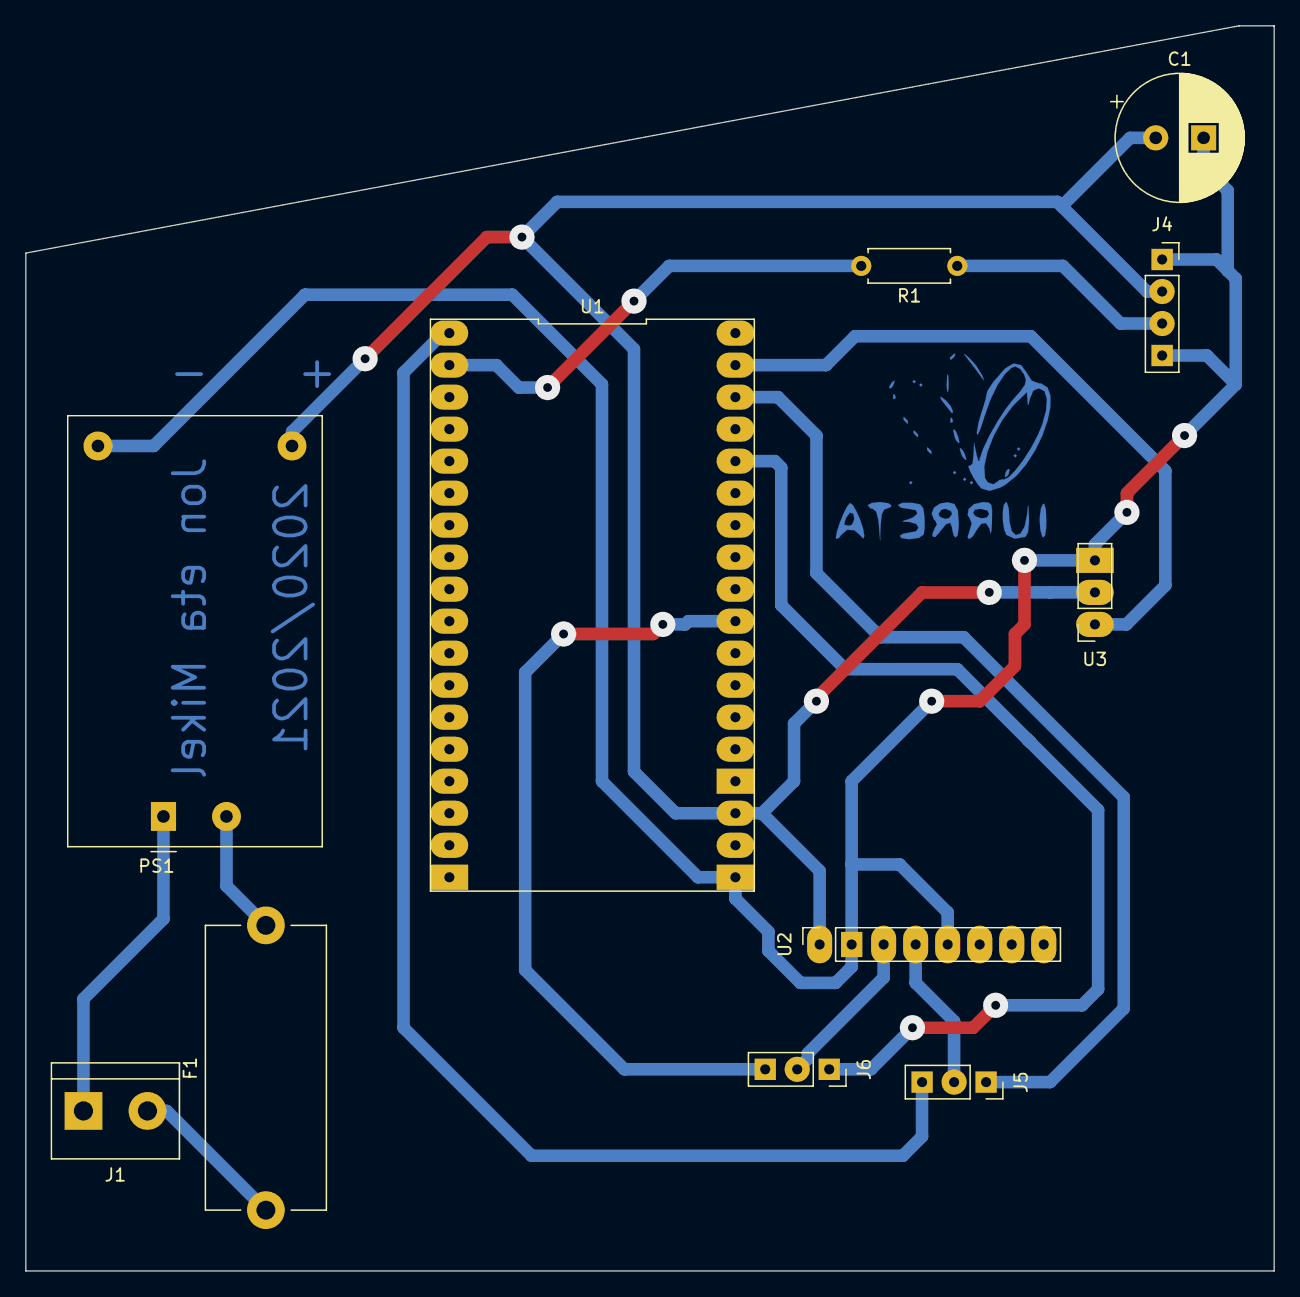
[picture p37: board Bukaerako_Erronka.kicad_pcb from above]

Board: 2 copper layers, 99.1 x 98.8 mm, 11 parts (0 on the bottom side), 14 nets.

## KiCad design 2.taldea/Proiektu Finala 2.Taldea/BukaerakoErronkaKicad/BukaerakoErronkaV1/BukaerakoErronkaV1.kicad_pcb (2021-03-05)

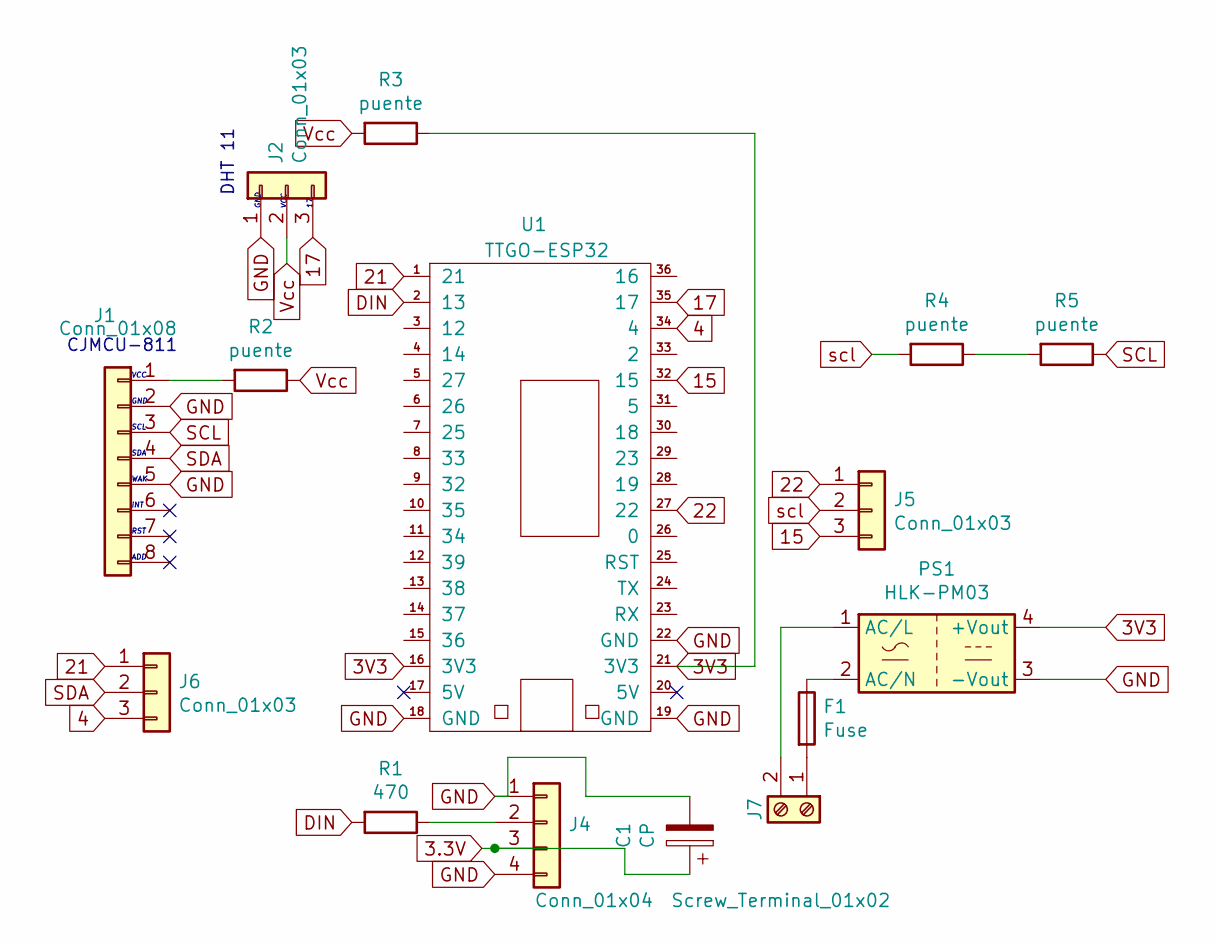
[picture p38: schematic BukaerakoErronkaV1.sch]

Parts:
C1: CP; CP_Radial_D10.0mm_P3.80mm
F1: Fuse; Fuseholder_Cylinder-5x20mm_Stelvio-Kontek_PTF78_Horizontal_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
J1: Conn_01x08; JST_EH_B8B-EH-A_1x08_P2.50mm_Vertical
J2, J5, J6: Conn_01x03; JST_EH_B3B-EH-A_1x03_P2.50mm_Vertical
J4: Conn_01x04; JST_EH_B4B-EH-A_1x04_P2.50mm_Vertical
J7: Screw_Terminal_01x02; TerminalBlock_bornier-2_P5.08mm
PS1: HLK-PM03; Converter_ACDC_HiLink_HLK-PMxx
R1: 470; R_Axial_DIN0207_L6.3mm_D2.5mm_P7.62mm_Horizontal
R2: puente; R_Axial_DIN0207_L6.3mm_D2.5mm_P15.24mm_Horizontal
R3, R4, R5: puente; R_Axial_DIN0207_L6.3mm_D2.5mm_P7.62mm_Horizontal
U1: TTGO-ESP32

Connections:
3.3V: C1.1, J4.3
3V3: PS1.4 (+Vout), R3.1, U1.16 (3V3), U1.21 (3V3)
4: J6.3, U1.34 (4)
15: J5.3, U1.32 (15)
17: J2.3, U1.35 (17)
21: J6.1, U1.1 (21)
22: J5.1, U1.27 (22)
DIN: R1.2, U1.2 (13)
GND: C1.2, J1.2, J1.5, J2.1, J4.1, J4.4, PS1.3 (-Vout), U1.18 (GND), U1.19 (GND), U1.22 (GND)
unnamed: F1.1, PS1.2 (AC/N)
unnamed: F1.2, J7.1
unnamed: J1.1, R2.2
unnamed: J4.2, R1.1
unnamed: J7.2, PS1.1 (AC/L)
unnamed: R4.1, R5.2
SCL: J1.3, R5.1
SDA: J1.4, J6.2
Vcc: J2.2, R2.1, R3.2
scl: J5.2, R4.2

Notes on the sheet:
DHT 11
CJMCU-811
VCC
GND
SCL
SDA
WAK
INT
RST
ADD

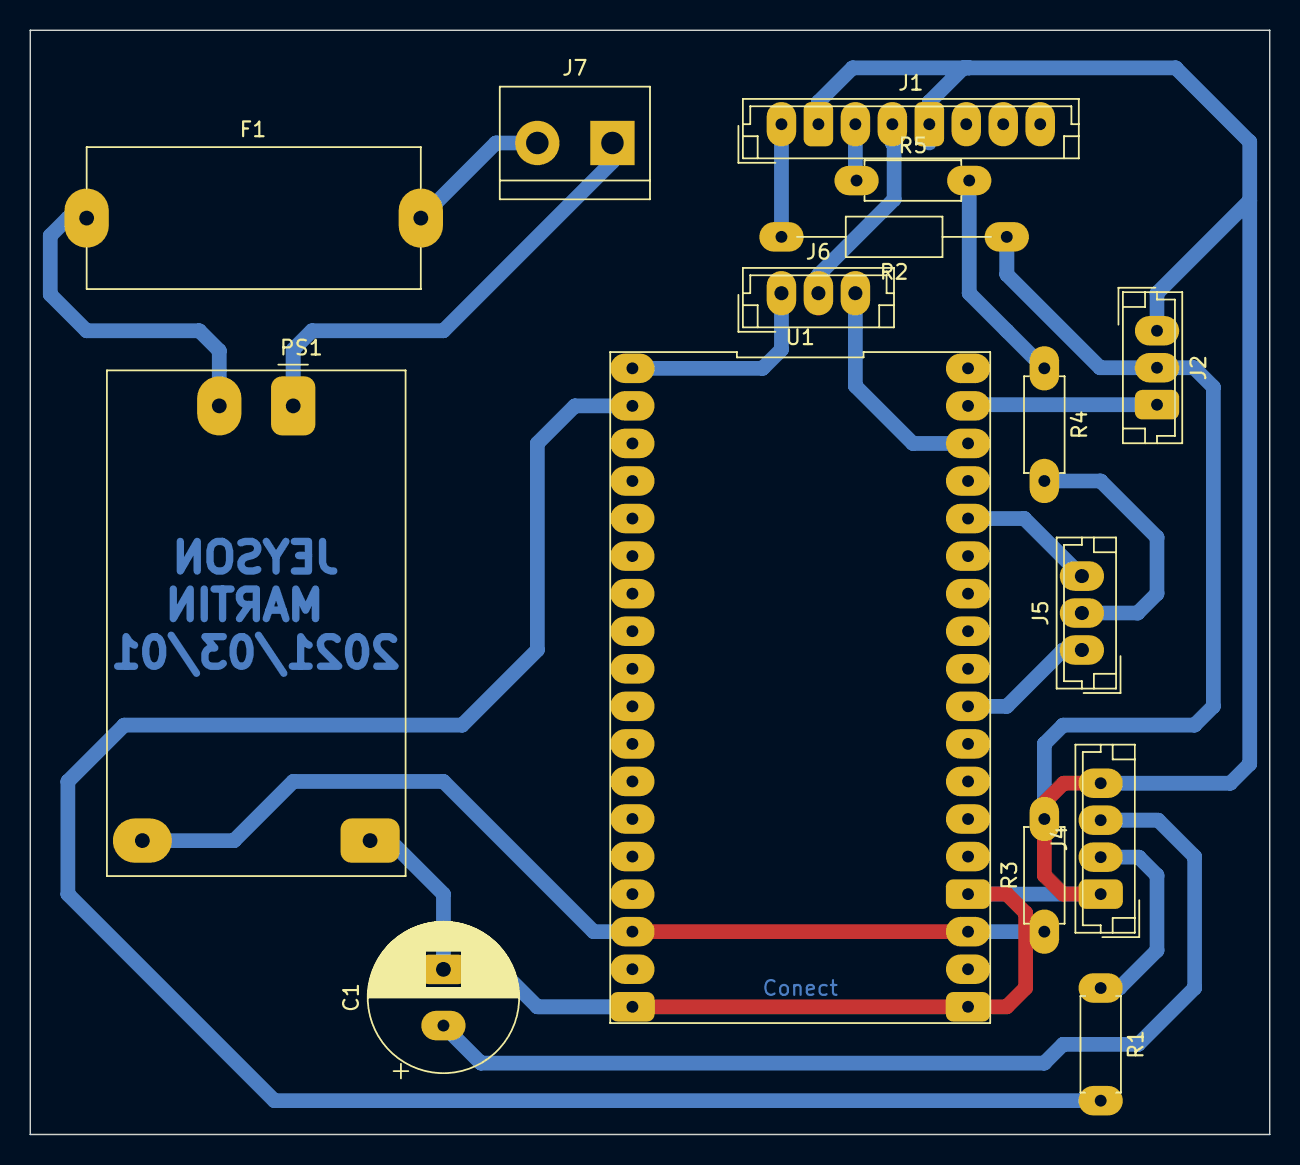
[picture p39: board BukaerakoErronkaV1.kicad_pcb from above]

Board: 2 copper layers, 83.8 x 74.7 mm, 15 parts (0 on the bottom side), 19 nets.

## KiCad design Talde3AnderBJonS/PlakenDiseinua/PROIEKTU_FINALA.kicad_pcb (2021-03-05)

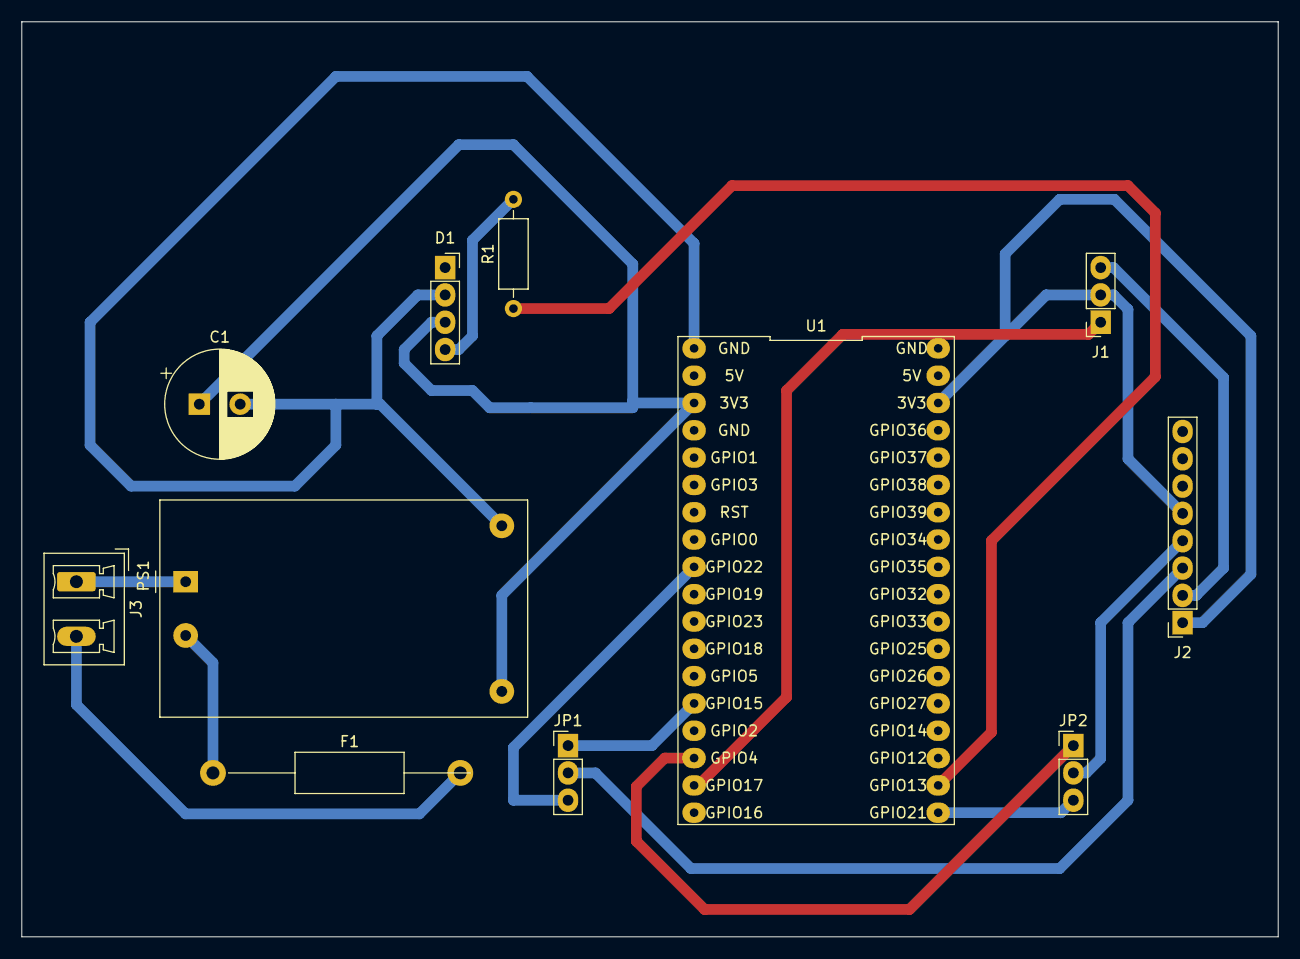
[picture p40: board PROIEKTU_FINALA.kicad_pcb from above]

Board: 2 copper layers, 116.8 x 85.1 mm, 11 parts (0 on the bottom side), 16 nets.

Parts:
C1: CP; CP_Radial_D10.0mm_P3.80mm
D1: NeoPixel_THT; PinSocket_1x04_P2.54mm_Vertical
F1: Fuse; R_Axial_DIN0411_L9.9mm_D3.6mm_P25.40mm_Horizontal
J1: Conn_01x03; PinSocket_1x03_P2.54mm_Vertical
J2: Conn_01x08; PinSocket_1x08_P2.54mm_Vertical
J3: Conn_01x02_Male; PhoenixContact_MCV_1,5_2-G-5.08_1x02_P5.08mm_Vertical
JP1, JP2: Jumper_3_Open; PinHeader_1x03_P2.54mm_Vertical
PS1: HLK-PM01; Converter_ACDC_HiLink_HLK-PMxx
R1: R; R_Axial_DIN0207_L6.3mm_D2.5mm_P10.16mm_Horizontal
U1: TTGO-ESP32; TTGO_ESP32

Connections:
unnamed: C1.1, D1.3, PS1.4, U1.3V3
unnamed: C1.2, D1.1, D1.2, PS1.3, U1.GND
unnamed: D1.4, R1.2
unnamed: F1.1, PS1.2
unnamed: F1.2, J3.2
unnamed: J1.1, U1.17
unnamed: J1.2, J2.1, J2.5
unnamed: J1.3, J2.2
unnamed: J2.3, JP1.2
unnamed: J2.4, JP2.2
unnamed: J3.1, PS1.1
unnamed: JP1.1, U1.15
unnamed: JP1.3, U1.22
unnamed: JP2.1, U1.4
unnamed: JP2.3, U1.21
unnamed: R1.1, U1.13

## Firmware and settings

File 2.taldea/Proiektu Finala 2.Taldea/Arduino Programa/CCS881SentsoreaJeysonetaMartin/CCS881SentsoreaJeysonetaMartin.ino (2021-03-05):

/*
 Programaren izena: CCS881SentsoreaJeysonetaMartin.ino
 Egilea: Elektronika    Data: 2021/02/22
 Zeregina: CCS881 sentsorea balioak irakurri eta portu seriean erakutsi
 Adibide hau domeinu publikokoa da.
 Programaren egoera: Egiaztatzeko/Egiaztatuta
 Egiaztatutako plakak: UNO ?? Nano Bai MEGA ???
 */
 
 /*-----( LIBURUTEGIAK )----*/
 #include "Adafruit_CCS811.h"
// - CCS881 Sensor Library: https://github.com/adafruit/Adafruit_CCS811


/*-----( KONSTANTEAK )-----*/
#define BAUDRATE 9600 //Komunikaziorako datuen abiadura
#define ITXARON 500 //Itxaroteko denbora

/*-----( OBJETUAK )-----*/
Adafruit_CCS811 ccs;

void setup() {
   Serial.begin(BAUDRATE);
 
  Serial.println("CCS811 test");
 
  if(!ccs.begin()){
    Serial.println("Failed to start sensor! Please check your wiring.");
    while(1);
  }
 
  // Wait for the sensor to be ready
  while(!ccs.available());
}

void loop() {
 if(ccs.available()){
    if(!ccs.readData()){
     //Serial.print(ccs.calculateTemperature());
     Serial.print("CO2: ");
      Serial.print(ccs.geteCO2());
      Serial.println("ppm");
      Serial.print("TVOC: "); 
      Serial.println(ccs.getTVOC());
   }   
    else{
      Serial.println("ERROR!");
      while(1);
    }
  }
  delay(ITXARON);
}

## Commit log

2021-03-05 Add files via upload
    .
    [CCS811.fzz, Copy of Caja con tapa (1).stl, DHT11.fzz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]
2021-03-05 Add files via upload
    Taldea3AnderBJonS
    [CCS811.fzzJONS ETA ANDER B.fzz, DHT.JONS_ANDERB.fzz, PROIEKTU_FINALA.kicad_pcb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]
